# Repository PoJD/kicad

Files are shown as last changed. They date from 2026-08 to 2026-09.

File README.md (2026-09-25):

# kicad

Printed circuit boards. A container for all projects, successor to the older
`eagle` repo.

KiCad 10 — text formats, readable diffs, ERC and DRC running in CI through
`kicad-cli` without a GUI. The CI container image tracks the local major
version, because KiCad refuses to open files written by a newer one.

## Boards

| Board | Status | Description |
|---|---|---|
| [`canfuel/`](canfuel/) | design finished, `fab/` generated | fuel consumption converter for a VW PQ34 car, powered from the display it feeds |

The `canfuel` board is finished: schematic and PCB complete, ERC and DRC clean
with zero unconnected items, 24 parts on 55 × 45 mm and two layers, `fab/`
generated and committed. ⚠ **While a fabrication order is outstanding, do not
edit the board files** — `fab/` describes the commit that was sent, and an edit
makes it stop describing what is being made.

The harness is built, fitted and measured —
[`canfuel/docs/harness.md`](canfuel/docs/harness.md) is the procedure. **The
whole build path, across all three repositories, is
[`canfuel/docs/firmware/install.md`](https://github.com/PoJD/canfuel/blob/main/docs/firmware/install.md);**
the steps this repository owns are the board and the loom.

## Prerequisites

| For | What | Notes |
|---|---|---|
| opening and editing | **KiCad 10.x** | the **major** version matters, see below |
| the checks | **`kicad-cli`** | installed with KiCad, no separate download |
| `tools/check-*.py` | **Python 3** | no third-party packages |

```
kicad-cli version          # must print 10.x
```

**The major version is not a preference.** KiCad refuses to open files written
by a newer major version, so a mismatch is a hard failure rather than a
warning. CI runs the `kicad/kicad:10.0` container image and that image tracks
whatever is installed locally — bump the two together, never separately.

Nothing here needs a licence, an account or a plugin. Making the board also
needs no KiCad at all: `fab/` is generated and committed, so a fab house can be
given those files directly.

## Layout

```
lib/                symbols and footprints shared across projects
<board>/
  *.kicad_pro       project
  *.kicad_sch       schematic
  *.kicad_pcb       board
  fab/              gerbers, BOM, CPL — committed
  docs/             design documents, datasheets, and how to build the harness
```

For the `canfuel` board specifically, `canfuel/docs/` holds:

| File | Contents |
|---|---|
| `harness.md` | **making the loom and wiring it into the car** — a checklist, with the crimping, the connector cavities and the fuse |
| `pinout.md` | one-page reference for all three connectors |
| `harness-*.svg` | the connector and the four nets drawn from the real pad coordinates in `canfuel.kicad_pcb`, so they cannot disagree with the board |
| `assembly-orientation.svg` | **the figure to have open while soldering** — both sides of the board, and which way round each of the five parts that can go in backwards goes |
| `solder-check.md` | **after each joint** — for every pad on the board, where the meter must read zero and what it must stay open to, with the gap in millimetres |
| `implementation-plan.md` | how the board was designed, every number cited to a datasheet |
| `*.pdf` | the manufacturers' datasheets, listed in `NOTICE` as theirs |

`*.kicad_prl` is local state and does not belong in the repo (it is gitignored).

`fab/` is committed deliberately even though it is generated: for any board
that has been ordered it must be possible to find out exactly what was sent to
the fab.

## CI

`kicad-cli sch erc` and `kicad-cli pcb drc`. Both must pass before boards are
ordered. The workflow **fails if it finds no design files**, so a green run
always means something was actually opened and checked.

Two project-specific checks run alongside them: `check-netlist.py` and
`check-placement.py`.

## Related repositories

The `canfuel` board is one third of a project that needs all three
repositories. Clone them side by side.

**Building one?** [`canfuel/docs/firmware/install.md`](https://github.com/PoJD/canfuel/blob/main/docs/firmware/install.md)
is the whole path from three clones to a working device, in the order it has to
happen. Making up the harness — the part that lives in this repository — is
step 3 of seven.

| Repository | What it holds | Go there for |
|---|---|---|
| **`kicad`** (this one) | the converter board | the schematic, the PCB, `fab/`, and **`canfuel/docs/harness.md` — how to make the loom and wire it into the car** |
| [`canfuel`](https://github.com/PoJD/canfuel) | the converter firmware | building and flashing the hex, what the LEDs mean, how the car's frames are decoded |
| [`mfd15`](https://github.com/PoJD/mfd15) | the display configuration | the TRI file the display runs and how to upload it |

**The coupling to `canfuel` is the pin assignment**, and it is one-way: the
firmware is written against the board, not the other way round. Changing it
means changing the firmware in the same breath, and invalidates any `fab/`
already sent.

## Licence

[Apache License 2.0](LICENSE). Use it, change it, order the boards, sell them —
the only obligations are to keep the copyright and licence notices and to say
what you changed.

**`NOTICE` lists what is not ours.** The manufacturer datasheets under
`canfuel/docs/` belong to their manufacturers and are redistributed for
reference only; the licence above does not cover them and does not claim to.
Everything else in this repository is covered.

Questions, corrections and pull requests are welcome as issues on any of the
three repositories, or by email to Lubos Housa <luboshousa@gmail.com>.

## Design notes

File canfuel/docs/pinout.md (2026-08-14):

# Connector pinout

The one page to look at when a wire is in your hand and you need to know which
cavity it goes in. It covers the three connectors this project touches: the two
plugs on the MFD15 and the plug that goes onto the converter board.

Connector pinout

**Every view is the rear / cable side of the connector**, which is the
convention the MFD15 manual sets and the only one worth having: it is the view
you have in front of you while you push crimps in. Section 2 of the manual puts
it plainly — *"All pinout diagrams show the rear/cable side of the connector.
Pin the wires exactly as shown in this view — do not mirror or rotate them."*
The same rule applies to everything below.

**Go by the latch, and the numbering stops looking arbitrary.** Every one of
these housings numbers from the corner away from the latch: circuit 1 sits
bottom right when the latch is up. Plugs A and B on the MFD15 have the latch
up, so they read `A4 A3 / A2 A1` and `B6 B5 B4 / B3 B2 B1` — pin 1 bottom
right. **Plug C is mounted upside down on the MFD15 body**, latch down, so the
same rule puts pin 1 top left and the numbers run `C1…C6` along the top. It is
one rule seen from two ways up, not two conventions, and the latch in each
drawing is what tells you which. The converter plug has its latch up, like A
and B.

The latch positions were read off the hardware, not off a drawing — no document
in either repository states them.

---

## Plug C — Molex 43025-1200, on the MFD15

Twelve circuits, of which this project uses four.

| Pin | Signal | Ours | Wire |
| --- | --- | ---- | --- |
| C6  | 5 V | yes  | red |
| C7  | CAN H  | yes  | white  |
| C8  | CAN L  | yes  | yellow |
| C12 | SGND | yes  | black  |

The other eight (C1 MPP 1, C2 AIN1, C3 AIN2, C4 AIN3, C5 AIN4, C9 AIN5,
C10 AIN6, C11 MPP 2) belong to the display and are not wired here.

**C7 and C8 were already crimped and are not to be disturbed** — they are the
display's own CAN pins. C6 and C12 are the two sockets this project adds.

## Plug B — Molex 43025-0600, on the MFD15

| Pin | Signal | Ours |
| --- | --- | ---- |
| B5  | 12 V | no |
| B6  | GND | no |
| B1–B4 | USB | no |

This is the display's own supply from the car. **Nothing on plug B feeds the
converter** — the converter's 5 V comes from plug C, and the 12 V branch was
dropped from the board design.

## Converter plug — Molex 43025-0400

Mates with J1 or J2 on the canfuel board; both headers are on the same four
nets, so either will do.

| Circuit | Net  | Wire | From |
| --- | ---- | --- | --- |
| 1 | +5V  | red | plug C6 (through the fuse) |
| 2 | SGND | black  | plug C12 |
| 3 | CANH | white  | plug C7  |
| 4 | CANL | yellow | plug C8  |

Circuits 1 and 2 are the row nearest the PCB; 3 and 4 the row further from it.
The latch is up and the moulded `1` is the bottom right cavity, so **3 sits
directly above 1 and 4 diagonally from it**.

---

## Where these numbers come from

- **The converter plug's signal names are read out of `canfuel.kicad_pcb`**,
  not typed in — the figure is generated from the pad nets of J1, so it cannot
  drift from the board. The order itself is fixed by implementation-plan 3.4.
- **Plugs B and C are transcribed from the MFD15 Gen2 manual Rev 1.0**,
  section 2 and Figure 1, in the sibling repository at
  `mfd15/docs/manual-mfd15-gen2.pdf`. The manual is the authority; if this page
  ever disagrees with it, the manual wins and this page is the bug.
- **C6 = 5 V and C12 = SGND were confirmed with a multimeter** (5.01 V). That
  is a fact about the car, not about a part, so it is settled by measurement —
  see the sourcing rule in the top-level `CLAUDE.md`.

- **The latch positions are observed**, on the plugs and on the display body.
  They are the only thing on this page with no document behind them, and they
  are also what makes the rest of it legible.

**One useful cross-check fell out of the manual.** The display's own plug A is
a Molex **43025-0400** — the same housing as the converter plug — and Figure 1
draws it, cable side, as `A4 A3` over `A2 A1`. Circuit 1 bottom right is
exactly how the physical housings are moulded, so the cavity layout is now
corroborated by a document rather than resting on convention alone.

What that still does not prove is that circuit *n* of the receptacle mates with
circuit *n* of the header — that much is Micro-Fit convention, and no datasheet
in this repository states it. **Ringing circuit 1 out to the board's +5V pad
before the first power-up is what closes it**, and it takes a minute. Swapping
CAN H and CAN L only stops the bus working; a CAN wire in circuit 1 or 2 meets
5 V, which plan 3.4 calls a dead transceiver.

## See also

- `harness.md` — building the loom, step A4a for fitting these crimps
- `car-wiring.md` — the fourth connector, the 12 V 4-pin between the car and the
  display's harness, and which colour is tapped where in the car
- `harness-connector.svg` — the plug and the board pads side by side
- `harness-nets-on-pcb.svg` — the same four nets on the real copper
- `implementation-plan.md` 3.4 — why the pin order is what it is

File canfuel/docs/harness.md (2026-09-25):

# Building the harness

The loom that connects the MFD15 to the car and to the converter board. It
carries two things: the CAN pair from the cluster to the air vent, and 5 V from
the display's own plug C to the converter.

> **Built, fitted and measured on a reference vehicle.** The dashboard came
> apart, the old loom came out, and a complete new one went in — longer 12 V
> and ground into the display's plug B, the CAN pair and the 5 V/SGND run
> terminating in the Micro-Fit that the converter board plugs into.
> **5.01 V measured at the 4-pin itself**, which is the number that
> matters: it is the supply the board will see, through the fuse and both
> splices, not a reading taken at plug C before the loom existed. The display
> was then run on this loom with the CAN pair on DuPont jumpers in place of the
> board, and it worked.
>
> **What this document does not cover is the board**, only the loom. See
> `canfuel/docs/firmware/install.md` step 4.
>
> The checkboxes below are deliberately left unticked: this is the procedure
> for building one, and everything learnt while building ours has been folded
> back into the steps rather than recorded as ticks. The one place ours
> deviates from the plan is D2, and it says so there.

**The measuring and the sniffing are done.** The supply was checked at C6/C12
and reads 5.01 V, the TRI file loads and the logs were taken. Everything that
was in this document about proving those points has been removed — what is left
is how to make the loom.

**The car-side 4-pin connector is settled too.** It exists and is already
fitted; this is a re-crimp onto longer wires, not a new connector choice.
`car-wiring.md` records what each of its wires is and where it is tapped in the
car — its circuit order is **not** the converter plug's, so read it before
assuming.

**What you need:** crimping pliers, pin extractors, multimeter, spare ACI pins,
spare Micro-Fit 43030 sockets, butt splices with adhesive-lined heat shrink,
cable ties, fabric loom tape.

---

## A. On the bench — making up the loom

- [ ] **A1. Test crimp on an ACI pin first.** Take a spare pin and crimp it
  onto 0.5 mm² FLRY with the pliers (second jaw position, 22–18 AWG). Pull on
  the wire — it must hold. Slide on the yellow seal, insert it into the
  housing; it must click and the red lock must go on.
  - ❗ If it does not hold, you need a second pair of pliers for waterproof
    connectors. Find that out now, on the bench, not with the dashboard in
    pieces.
- [ ] **A2. Cut the new wires.** Red and black for the power run to plug B,
  yellow and white for the long CAN run from the cluster to the air vent. Err
  on the long side — shortening is always possible and this is a re-crimp
  precisely because the first set came out short.
- [ ] **A3. Twist the CAN pair** along its whole length.
- [ ] **A4. Crimp the ends.** ACI pins on the car side, Micro-Fit 43030 sockets
  on the housing side. Tug every one by hand.
- [ ] **A4a. Fit the sockets into the 4-pin Micro-Fit housing (43025-0400) in
  the right cavities.** The order is fixed by plan 3.4 and matches the pads of
  J1/J2 on the board. **Work it out before crimping, not mid-build.**

  | Micro-Fit circuit | Net  | Wire   | Plug C |
  | ----------------- | ---- | ------ | ------ |
  | 1                 | +5V  | red    | C6     |
  | 2                 | SGND | black  | C12    |
  | 3                 | CANH | white  | C7     |
  | 4                 | CANL | yellow | C8     |

  **Find the cavities from the moulded `1`, not by counting from an end** —
  seen from the wire side the numbering is the mirror of what it is from the
  mating face, so counting is exactly how this gets swapped. Circuits 1 and 2
  are the row the `1` belongs to; 3 and 4 are the other row, with **3 directly
  across from 1** and 4 diagonally opposite it. So the white wire goes across
  from the `1`, the yellow one diagonally from it.

  On the housings actually bought (moulded `MSH`), held wire-side towards you
  with the board header behind, the `1` is the **bottom right** cavity, so:

  ```
      4 CANL yellow    3 CANH white     upper row
      2 SGND  black    1 +5V   red      lower row, nearer the PCB
  ```

  That is the same way round as the board: J1/J2 pad 1 (+5V) is the right-hand
  pad of the row at the board edge and pad 3 (CANH) sits directly behind it,
  because the lower row of a right-angle header is the one nearest the PCB.

  `pinout.md` next to this file is the one-page connector reference for all
  three plugs, drawn the way the MFD15 manual draws its own.
  `harness-connector.svg` draws both — it is generated from
  the pad coordinates in `canfuel.kicad_pcb`, not drawn by hand, so it cannot
  disagree with the board. `harness-nets-on-pcb.svg` is the same four nets
  drawn on the real copper, turned the way up the 1:1 paper print comes out.

  **On a bare board the two pairs can be told apart by eye**: +5V is routed at
  0.8 mm and CANH/CANL at 0.4 mm, so the fattest tracks leaving the connectors
  are the power pair. SGND has no track at all — it is entirely the pour.

  ❗ Swapping CANH and CANL only stops the bus working. Putting a CAN wire in
  circuit 1 or 2 puts **5 V on it** — plan 3.4 calls that a dead transceiver.
  So **ring circuit 1 out to the board's +5V pad before the first power-up**,
  which is also the only check that catches a housing whose numbering does not
  follow the header's.
- [ ] **A5. Fit two sockets (5 V, SGND) into the existing 12-pin housing of
  plug C**, positions C6 and C12. **Do not touch C7/C8** — those are the
  display's CAN pins and they are already right.
- [ ] **A6. Ring everything out.** Every wire end to end, and no short between
  adjacent positions. Do this before the fuse goes in, so that a later failure
  has only one new thing to blame.

## B. On the bench — the 5 V fuse

The converter takes 5 V straight from the display, so a short on the converter
board is a short across the MFD15's 5 V rail. The fuse ends that. It is in the
loom rather than on the board because no 5 × 20 holder fits on a finished
55 × 45 mm PCB — plan 9.2 has the measurements and the reasoning.

**Parts:** SIBA 179120.0.2, 200 mA 250 V 5 × 20 mm glass, **time-lag T** — not
the fast F version — in inline cable holder K23411, which comes with 200 mm of
lead. The holder body is about 46 mm long and 10.5 mm across, so it needs a
straight run of loom that length and somewhere it can be unscrewed.

- [ ] **B1. Cut the 5 V wire only**, a short way back from the 4-pin connector
  at the air vent end. Leave the ground wire whole. Place the cut so the holder
  ends up in the length of loom that comes out when the MFD15 is pulled — the
  whole point is that the fuse can be changed without dismantling the dash.
- [ ] **B2. Join each cut end to one lead of the holder.** Crimp butt splices
  with adhesive-lined heat shrink are the right way. Soldering is acceptable if
  the joint is then sleeved well past the wick on both sides — a soldered joint
  in a loom that vibrates cracks exactly at the edge of where the solder
  travelled.
- [ ] **B3. Cable-tie the holder to the loom** so it cannot swing and chafe
  against the vent housing.
- [ ] **B4. Ring it out again** — continuity from plug C position C6 through to
  the 4-pin, with the fuse fitted. Then pull the fuse and confirm the circuit
  really does open. That second half is the one worth doing: it proves the fuse
  carries the current and that no splice quietly bypasses it.

## C. In the car — routing

- [ ] **C1. Take the dashboard apart** (radio, centre panel).
- [ ] **C2. Route the long CAN run** from the cluster to the air vent, so that
  the connector can be pulled out of the vent.
- [ ] **C3. Route the power wires** from the car's 4-pin to plug B. **This is
  12 V for the MFD15 itself, not for the converter.** The converter's 5 V comes
  from plug C at C6/C12 and never touches plug B — the 12 V branch was dropped
  from the board design, so nothing in this step feeds the converter.
- [ ] **C4. Do not tape anything up yet.** Loom it right at the end, once
  everything is in place and reaches.

## D. Finishing

- [ ] **D1. Tape up the looms and tidy the routing.** Use **fabric loom tape,
  not PVC insulating tape** — at dashboard temperatures PVC adhesive creeps,
  which is the same reason the board is not taped down either.
- [ ] **D2. ~~Wrap up to the fuse holder and start again after it.~~
  Overridden on the build: the holder is wrapped over as well.** The intent
  was that the fuse could be changed without unwrapping anything. On the
  actual holder one end leaves **bare 5 V exposed**, and bare metal loose
  behind a dashboard was judged the worse of the two risks, so it is taped
  over along with the rest of the loom.

  **What that costs:** changing a fuse now means peeling the tape back and
  re-wrapping it. So **the spare fuse in the car is not enough on its own —
  a roll of the fabric tape has to travel with it**, or the roadside repair
  cannot be finished.

  The alternative, if this is ever rebuilt: sleeve only the exposed end and
  leave the holder body outside the tape, which gets both. Not worth
  dismantling a finished loom for.
- [ ] **D3. Reassemble the dashboard.**

---

## If the fuse blows

The fault is on the converter board, not in the display. Fit one new fuse — and
carry a spare **and a roll of the fabric tape**, because the holder is wrapped
over (see D2) and a blown fuse behind the dash with nothing to hand is a wasted
trip. If the second one goes as well, stop replacing fuses and find
the short. That is what the fuse is telling you.

**What the fuse does not protect:** the run from plug C to the fuse itself.
That is deliberate — it lies inside the dashboard and does not move, and
covering it would mean putting the fuse somewhere you cannot reach.

## If a crimp will not hold

Stop and sort the tool out before going any further. A crimp that needs
persuading on the bench is a crimp that will let go in the car, and everything
downstream of this loom is inside a dashboard.

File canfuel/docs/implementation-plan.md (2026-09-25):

# canfuel — implementation plan

How to get from an empty repository to an ordered board. The requirements in
the root `CLAUDE.md` are the input and are treated as settled; this document
turns them into reference designators, nets and pin numbers.

Read the killer checks in section 3 before drawing anything.

**This is a design reference, not a progress tracker.** What is left to do in
the project as a whole lives in one place:
[`canfuel/docs/firmware/install.md`](https://github.com/PoJD/canfuel/blob/main/docs/firmware/install.md).

> ⚠ **This document was written before the board was drawn, and the board is
> now made.** Most of it is still the reference — the pin table in 4.2, the
> footprints in 4.7, the fab commands in 6 — but where the design moved after
> the plan was written, the plan has been corrected in place rather than
> rewritten, with the old text quoted and dated so a decision cannot be mistaken
> for an oversight.
>
> **The big one is the escape header J4**, removed because routing put a number
> on what it cost: eight unroutable connections, five of them nothing to do
> with the escape signals. Section 5.4 is the full account, and
> `canfuel/docs/firmware/refuted.md` entry D1 is the short one. Fourteen pins that this
> document originally sent to J4 now go **nowhere**, and driving them low is a
> firmware obligation — see 3.6.
>
> `canfuel/docs/firmware/refuted.md` collects every idea in this project that was
> believed and turned out wrong, across all three repositories.

**Every electrical number below is cited to a manufacturer datasheet**, per the
sourcing rule in `CLAUDE.md`. The three documents are in `docs/`:

| Short form | Document |
| --- | --- |
| `DS39977C` | Microchip, PIC18F66K80 family — `pic18f25k80-datasheet.pdf` |
| `DS20005167C`| Microchip, MCP2561/2 — `mcp2562-datasheet.pdf` |
| crystal d/s  | HC-49U/S DIP quartz crystal resonator — `crystal-datasheet.pdf` |
| Hitano EXR | C6's electrolytic — `hitano-exr-datasheet.pdf` |

Section 10 lists what has actually been read out of them, so the next person
can tell a checked number from an inherited one.

---

## 0. Prerequisites — done

- [x] **KiCad 10.0.5** installed to `C:\Program Files\KiCad\10.0`. The GUI,
      `kicad-cli.exe` and the standard symbol/footprint libraries all come from
      the one installer; there is no separate CLI download.
- [x] **`C:\Program Files\KiCad\10.0\bin\` added to the user PATH by hand.**
      The Windows installer does not do it (KiCad issue #19639), so without
      this `kicad-cli` only works inside the "KiCad Command Prompt" shortcut —
      fine interactively, useless for a script or a git hook. A shell that was
      already open when the PATH was edited still will not see it.
- [x] `kicad-cli version` prints `10.0.5`; `sch erc` and `pcb drc` both accept
      `--exit-code-violations`, which is what CI relies on.

**The major version is load-bearing.** KiCad cannot open files written by a
newer major version, so the CI image in `.github/workflows/kicad.yml` is pinned
to `kicad/kicad:10.0` to match. Upgrading one without the other breaks CI.

---

## 1. Project skeleton — done, its own commit

The project was created with the KiCad GUI (`File → New Project`) so the
generated files carry the correct schema versions; they are not hand-written.

```
canfuel/
  canfuel.kicad_pro
  canfuel.kicad_sch      empty
  canfuel.kicad_pcb      outline only
```

Board Setup, applied before any drawing:

| Setting | Value | Where it lives |
| --- | --- | --- |
| Layers | 2 (F.Cu, B.Cu) | `.kicad_pcb` `(layers)` |
| Copper thickness | 1 oz / 35 µm | `.kicad_pcb` `(setup (stackup))` |
| Board thickness | 1.6 mm | `.kicad_pcb` `(general (thickness))` |
| Minimum track width  | 0.20 mm | `.kicad_pro` `design_settings.rules` |
| Minimum clearance | 0.20 mm | same |
| Minimum via | 0.6 mm pad / 0.3 mm drill | same |
| Minimum hole/annulus | 0.30 mm / 0.15 mm | same |

**The board outline is in this commit too**, ahead of section 5.1. It has to
be: DRC reports `invalid_outline` as an error on a board with no Edge.Cuts
edges, so without it the skeleton commit could not be CI-green. It is the
settled 55 × 45 mm with R2 corners, origin at (50, 50) on the sheet. The four
M3 mounting holes went in later, once dropping the enclosure (section 9.1) made
their positions ours to choose.

**Definition of done:** CI green on a repository that contains an empty
schematic and a board that is an outline and nothing else. ✔

---

## 2. Parts and reference designators

> **Naming note.** The display's connector pins are called C6, C7, C8, C12 in
> the requirements. Capacitors on this board are also C-something. Below,
> connector pins are always written as **plug C pin 6**, never `C6`.

| Ref | Part | Package / footprint | Note |
| --- | --- | --- | --- |
| U1 | PIC18F25K80 | PDIP-28, **narrow 7.62 mm** socket | in a socket, never soldered direct |
| U2 | MCP2562-E/P | DIP-8 socket | in a socket. `-E/P` is the DIP part |
| Y1 | 16 MHz crystal, CL = 20 pF  | HC-49/S | **CL must be specified** — see 3.2 |
| C1, C2 | 33 pF C0G | 2.54 mm THT | **33 pF, not 22 pF** — see 3.2 |
| C3 | 100 nF X7R | 2.54 mm THT | U1 VDD (pin 20) |
| C4 | 100 nF X7R | 2.54 mm THT | U2 VDD (pin 3) |
| C5 | 100 nF X7R | 2.54 mm THT | U2 VIO (pin 5) |
| C6 | 10 µF electrolytic, 16 V | 5 mm THT radial | supply input; **105 °C part** — see 7  |
| C7 | 10 µF X7R, 16 V, **Murata GRM32DR71C106KA01L** | 1210 SMD | **mandatory** — U1 VDDCORE/VCAP, see 3.5 |
| C8 | 100 nF X7R | 2.54 mm THT | MCLR reset hold, behind JP2 — see 4.3a |
| R1 | 10 kΩ | 1/4 W THT | MCLR pull-up |
| R2 | 10 kΩ | 1/4 W THT | RA0 pull-down (debug jumper) |
| R3, R4 | 1 kΩ | 1/4 W THT | LED series resistors — see 3.6 |
| R5 | 120 Ω | 1/4 W THT | **DO NOT FIT** — see 3.3 |
| R6 | 470 Ω | 1/4 W THT | MCLR series — see 4.3a |
| D1 | LED **red** | 3 mm THT | power / heartbeat. Colour is free — see CLAUDE.md |
| D2 | LED yellow | 3 mm THT | CAN status |
| J1, J2 | Molex Micro-Fit 3.0 43045-0400 | right-angle, board mount | wired in parallel — see 3.4 |
| J3 | 5-pin header 2.54 mm | 1×5 | ICSP |
| ~~J4~~ | ~~2×8 header 2.54 mm~~ | — | **removed — see 5.4** |
| JP1 | 2-pin header + jumper | 1×2 | debug enable on RA0 |
| JP2 | 2-pin header + jumper | 1×2 | isolates C8 for programming — see 4.3a |
| — | DIP-28 socket, narrow | | not in `canfuel-bom.csv` — see 7 |
| — | DIP-8 socket | | not in `canfuel-bom.csv` — see 7 |

---

## 3. The things that quietly kill this board

Check each one twice while drawing, and again during the ERC pass. All of them
are now on the sheet as drawn, and all of them are repeated as numbered notes
in the schematic's own notes panel so they survive without this file.

### 3.1 MCP2562 VIO and STBY

The single easiest mistake in the design. Without these the transceiver sits in
standby and transmits nothing, while everything else measures fine.

**STBY floating is not neutral — it is Standby.** DS20005167C section 1.7.9:
STBY carries an internal MOS pull-up to VIO, typically 660 kΩ at 5 V. An
unconnected pin 8 therefore reads high, and section 1.1.2 says a high on STBY
switches the transmitter off. That is why pin 8 is tied hard to SGND rather
than left to a resistor or a jumper that assembly could skip.

The datasheet's own application circuit (Figure 1-2) drives STBY from an MCU
pin instead, which buys a low-power standby mode. **We deliberately do not**:
the board is powered only while the display is, and total draw is under 30 mA
against a 0.5 A budget, so standby is worth nothing here and a hard ground
removes a whole class of failure.

MCP2562 DIP-8 pinout, from DS20005167C page 1 (package types) and Table 1-2:

| Pin | Name | Connect to |
| --- | ---- | --- |
| 1 | TXD  | U1 RB2 (CANTX), pin 23 |
| 2 | VSS  | SGND |
| 3 | VDD  | +5V (with C4 across pins 3–2) |
| 4 | RXD  | U1 RB3 (CANRX), pin 24 |
| 5 | VIO  | **+5V** (with C5 to SGND) |
| 6 | CANL | CANL |
| 7 | CANH | CANH |
| 8 | STBY | **SGND** |

Do not leave pin 8 floating and do not leave pin 5 unconnected on the
assumption it is optional. Tie them hard — no pull-ups, no jumpers, nothing
that could be left off during assembly.

VIO is a supply, not a logic input: DS20005167C 2.2 gives its range as
1.8–5.5 V, and 1.1.2 notes the bus wake-up needs **both** VDD and VIO in range.
Figure 1-2 shows 0.1 µF on each — that is C4 and C5. VDD itself is specified
4.5–5.5 V, so the 5 V rail sits mid-range.

### 3.2 Crystal loading is 33 pF

C1 = C2 = **33 pF** C0G/NP0, not the 22 pF that gets fitted by reflex, and not
X7R.

The number comes out of the crystal datasheet rather than habit. That sheet
gives **Loading Capacitance: 20 pF Std., 8 to 33 pF**, and its own part-number
example for this frequency — `FTX16.000M20S-30/30B` — is a 16.000 MHz part with
CL = 20 pF in the HC49/S package. So:

```
CL = C1·C2/(C1+C2) + Cstray,  and with C1 = C2 = C:
C  = 2·(CL − Cstray) = 2·(20 − 5) = 30 pF  →  33 pF from the E12 row
```

Cstray of about 5 pF is the usual allowance for the pads, tracks and pin
capacitance on a through-hole board of this size.

> **An earlier version of this document said CL = 32 pF.** That figure appears
> nowhere in the crystal datasheet and does not survive the arithmetic above —
> a 32 pF crystal would want about 56 pF, and 33 pF caps would have run it
> fast. The capacitor value was right for the wrong reason, which is exactly
> the failure mode the sourcing rule in `CLAUDE.md` exists to catch.

Two independent confirmations that 33 pF is the right pairing: the calculation
above, and `PoJD/can-pcb` — `CanSwitch.sch` and `CanRelay.sch` both run a
16 MHz HC49/S with 33 pF and have worked for years.

**No series resistor on OSC2.** DS39977C Table 3-3 note 2 says an Rs "may be
required to avoid overdriving crystals with low drive level specification", and
this crystal's drive level is 100 µW typical, 500 µW maximum. Whether it is
actually needed cannot be decided from the datasheets — it takes a measurement
on a built board. The same PIC-family part drives the same crystal without Rs
in `can-pcb`, so none is fitted. If the oscillator misbehaves, a series
resistor has to be tacked in at the socket pins, which are through-hole and
reachable from underneath.

Microchip's own tables are guidance only and do not cover this case directly:
Table 3-3 (crystals, HS) lists 27 pF at 4 MHz, 22 pF at 8 MHz and 15 pF at
20 MHz with no 16 MHz row, and note 3 defers to the crystal manufacturer for
the right values. That is what the derivation above does.

### 3.3 No 120 Ω termination

The car's bus is already terminated at both ends. A third resistor overloads
it. R5 gets a footprint and silkscreen, and is **not fitted**:

- Place R5 across CANH/CANL near U2. Done — (85.52, 91.5).
- Silkscreen next to it: `120R DNF`. Done — a board-level `gr_text` at
  (93.2, 91.5), added when the 6 pre-order check found it missing. It is not
  part of the R5 footprint, so re-running `import-footprints.py` cannot take it
  away again.
- Mark it `Do not populate` in the symbol's fields so it drops out of the BOM.
  Done — `in_bom no` and `dnp yes`; it is in neither `canfuel-bom.csv` nor
  `canfuel-cpl.csv`.

A separate solder jumper is not worth the area — for a bench test the resistor
has to be soldered in anyway, and an unpopulated footprint is exactly as quick.

### 3.4 Both Micro-Fit headers in parallel

J1 and J2 sit on the same four nets: CANH, CANL, +5V, SGND. Pin *n* of J1 goes
to pin *n* of J2. This is intentional: cables become interchangeable and the
board is a CAN pass-through even with U1 pulled out of its socket.

| Micro-Fit pin | Net  | Harness |
| --- | ---- | --- |
| 1 | +5V  | plug C pin 6 |
| 2 | SGND | plug C pin 12 (SensorGround) |
| 3 | CANH | plug C pin 7 |
| 4 | CANL | plug C pin 8 |

Fix this pin order once, here, and keep the harness (`harness.md`) consistent
with it. Getting +5V and CANH swapped is a dead transceiver.

### 3.5 VDDCORE/VCAP needs 10 µF — and pin 6 is not a port pin

Settled against the datasheet (DS39977C, section 2.4 "Voltage Regulator Pins",
section 28.3 and Table 31-4). Two things follow, and both are easy to get
wrong from memory:

**There is no ENVREG pin.** Not on the 28-pin package, not anywhere in the K80
family. On PIC18F parts (as opposed to PIC18**LF**) the on-chip 3.3 V core
regulator is *permanently enabled* — there is nothing to tie and no way to
disable it. VDD stays at 5 V and the I/O is 5 V; only the core runs at 3.3 V.

**Pin 6 is VDDCORE/VCAP, not RA4.** The 28-pin K80 has no RA4 at all. Pin 6
needs C7:

- **10 µF, low-ESR (< 5 Ω)**, ceramic or tantalum, from pin 6 to SGND.
  Table 31-4 gives CEFC as min 4.7 µF, typ 10 µF.

  **The fitted part is a Murata GRM32DR71C106KA01L**, 10 µF X7R 16 V in 1210 —
  one of the four Microchip names in Table 2-1, so no equivalence argument has
  to be made at all. Its ESR is tens of milliohms against a 5 Ω limit, and X7R
  in a 1210 case loses little enough to DC bias at 3.3 V to stay well clear of
  the 4.7 µF minimum.

  It is the only SMD part on the board, which is a deliberate trade. A dipped
  tantalum was the obvious through-hole alternative and was rejected: the CA42
  datasheet gives DF = 6 % at 100 Hz for the 10–68 µF range, which works out at
  9.6 Ω there and **specifies no high-frequency ESR at all**. The real figure
  is probably 2–3 Ω and `PoJD/can-pcb` has run one for years, but "probably"
  is not a specification, and this is the component whose failure mode the rest
  of this section describes as intermittent and nasty to debug. A tantalum
  would also have to become `C_Polarized` with polarity on the silkscreen —
  `can-pcb` drew its as a non-polarised `C-EU`, which worked only because the
  builder knew which way round it went.
- ⚠ **Pin 6 must never be connected to VDD.** That is the regulator's output,
  not an input. Tying it to 5 V destroys the part.
- Keep the trace to the capacitor **under 6 mm** (datasheet: 0.25 inch).

Without C7 the regulator is unstable and the part browns out or never starts —
and because the symptom is intermittent it is a genuinely nasty one to debug.

**The 0.1 µF figure is real but belongs to a different part.** DS39977C 2.4
gives it twice: once for "when the regulator is disabled", and once for the
PIC18**LF**XXKXX devices, which disable the regulator permanently. Our part is
an F, where 2.4 says the regulator is permanently *enabled* and "these devices
require a 10 µF capacitor on the VCAP/VDDCORE pin". Reading the sentence that
applies to the neighbouring part number is how a board ends up with 0.1 µF
there.

**Available port A pins.** With the crystal on pins 9/10, RA6 and RA7 are gone
and pin 6 is not a port pin, so port A offers exactly five usable pins:
**RA0 (2), RA1 (3), RA2 (4), RA3 (5), RA5 (7)** — of which RA0 is the debug
jumper. Port A is tight, and by 3.6 it is also weak; do not plan on more.

### 3.6 Port A can only drive 2 mA — the LEDs are on port C

DS39977C page 541, Absolute Maximum Ratings, splits the ports:

| Pins | Max sourced | Max sunk |
| --- | --- | --- |
| PORTA<7:6>, any PORTB, any PORTC  | 25 mA | 25 mA |
| **PORTA<5:0>**, PORTF, PORTG | **2 mA** | **2 mA** |

RA1 and RA2 are inside PORTA<5:0>. An LED at 1 kΩ off a 5 V rail draws about
2.2 mA once VOH is taken as VDD − 0.7 (D090) and Vf as 2.1 V — over the limit,
so **D1 and D2 are on RC0 (pin 11) and RC1 (pin 12)**, and RA1/RA2 were left
unused. R3 and R4 stay at 1 kΩ. (They "went to the escape header instead" until
J4 was removed, §5.4; on the manufactured board they go nowhere
and the firmware drives them low.)

Two things make this worth writing down rather than just fixing:

- **The datasheet contradicts itself and the stricter number wins.** D080/D090
  in the DC characteristics specify VOL and VOH for "PORTA, PORTB, PORTC"
  together, at IOL = 8.5 mA and IOH = −3 mA, which reads as permission to pull
  3 mA out of RA1. Absolute Maximum Ratings is a stress rating the manufacturer
  will not stand behind being exceeded; a characterisation table is not a
  licence to exceed it.
- **`can-pcb` was not a precedent for this.** Its status LED hangs off RC1
  through 1 kΩ — port C, 25 mA. The 1 kΩ was inherited from that board without
  the pin, and the pin was the part that mattered.

RA0 is unaffected: it is an input with a pull-down, and sources nothing.

### 3.7 J1/J2 — the Micro-Fit PCB layout, and why the holes are "finished"

`micro-fit-43045-datasheet.pdf` is Molex **SD-43045-001** (rev. 2016/08/23),
*Micro-Fit (3.0) Dual Row Right Angle Thru Hole Header Ass'y*. It was the last
part on the board with no datasheet on disk. Its `PCB LAYOUT: COMPONENT SIDE`
block settles four things that had only ever been taken from the KiCad
footprint:

| Drawing | Value | As built |
| --- | --- | --- |
| contact hole | ⌀ .040±.002 / **1,02±0,05 mm** TYP | 1.02 mm |
| peg hole | ⌀ .118±.002 / **3,00±0,05 mm** TYP | 3.00 mm NPTH |
| pitch | .118±.004 / 3,00±0,10 non-accum | 3.00 mm |
| row spacing | .170±.003 / 4,32±0,08 | ok |
| recommended board thickness | .062 / **1,57 mm** | 1.60 mm |
| mates with | receptacle series **43025** | 43025-0400 bought |

The pin itself is **.025 / 0,64 mm SQ TYP**, so its diagonal is 0.905 mm.

**Note 7 of the drawing is a placement rule and nobody had checked it:** *"To
avoid interference between receptacle and PCB, header must be placed within
.400/(10,16) max. from edge of PCB."* It limits how far the header may be set
back, so the mating receptacle does not foul the board. J1 and J2 courtyards
end **0.33 mm** from the bottom edge — effectively flush, against a 10.16 mm
limit. It passes with room, but it passes by luck rather than by design, so it
is written down now: if these connectors are ever moved inward, this is the
number that decides it.

**The holes must be ordered as finished sizes, not drill sizes.** A fab that
compensates for plating turns a 1.02 mm tool into a 0.92 mm finished hole,
which is below the drawing's 0.97 mm lower limit — out of spec. Asked the other
way the error is benign: a hole 0.1 mm too large loosens the pin and drops the
annular ring to 0.19 mm, still far above any fab's minimum. So "finished" is
both correct and the safe direction. See 6.1.

**The peg hole is the fussy one, and the answer is not a smaller number.** The
plastic peg is split and spreads under the board, so the instinct is to
undersize the hole for grip. Molex already allowed for that: ±0.05 mm is the
band the peg is designed to hold across. Moving the nominal down to 2.95 or
2.97 puts the low end of any normal fab tolerance under 2.95 and out of spec,
and forcing a split LCP peg into an undersized hole is how the housing cracks —
on a right-angle part the peg also carries the plug insertion force.

The real hazard is plating, not the nominal. A **plated** peg hole comes out at
about 2.90 mm, under the 2.95 minimum, which is exactly the "have to force it"
failure; and plating compensation wrongly applied to a hole that is not plated
gives 3.10 mm, where the peg does not grip at all. Both are avoided by shipping
PTH and NPTH as separate drill files and saying which is which — see 6.

---

## 4. Schematic — done

One A3 sheet. A4 was tried first and everything collided; the parts count is
low but the label count is not.

### 4.1 Nets

```
+5V      SGND      CANH      CANL
CAN_TX   CAN_RX    OSC1      OSC2
~MCLR    MCLR_RC   MCLR_C                (the reset network of 4.3a)
PGC      PGD       VCAP
LED_PWR  LED_CAN   DBG_EN                (LED_PWR/LED_CAN are RC0/RC1)
LED_PWR_A          LED_CAN_A             (resistor to LED anode)
CANTX2   CANRX2                          (RC6/RC7, the ECAN alternates)
ESC_RA1  ESC_RA2   ESC_RA3   ESC_RA5
ESC_RC2 … ESC_RC5
ESC_RB0  ESC_RB1   ESC_RB4   ESC_RB5
```

33 nets in total. `SGND` is the ground net name throughout, not `GND` — it is
the display's sensor ground and the harness documentation calls it that.

**The labels are global, not local.** On a single-sheet design either works
electrically, but a local label comes out of the netlist as `/CANH` while the
net classes in section 5.3 are written as `CANH`. A netclass pattern that
silently matches nothing is a bad way to find out that CAN was routed at the
default track width.

### 4.1a Symbol and footprint choices

| Ref | Symbol | Footprint |
| --- | --- | --- |
| U1 | `MCU_Microchip_PIC18:PIC18F25K80_ISS` | `Package_DIP:DIP-28_W7.62mm_Socket` |
| U2 | `Interface_CAN_LIN:MCP2562-E-P` | `Package_DIP:DIP-8_W7.62mm_Socket` |
| Y1 | `Device:Crystal` | `Crystal:Crystal_HC49-U_Vertical` |
| C1–C5 | `Device:C` | `Capacitor_THT:C_Disc_D5.0mm_W2.5mm_P5.00mm` |
| C6 | `Device:C_Polarized` | `Capacitor_THT:CP_Radial_D5.0mm_P2.00mm` |
| C7 | `Device:C` | `Capacitor_SMD:C_1210_3225Metric_Pad1.33x2.70mm_HandSolder` |
| R1–R5 | `Device:R` | `Resistor_THT:R_Axial_DIN0207_L6.3mm_D2.5mm_P10.16mm_Horizontal` |
| D1, D2  | `Device:LED` | `LED_THT:LED_D3.0mm` |
| J1, J2  | `Connector_Generic:Conn_02x02_Odd_Even` | `Connector_Molex:Molex_Micro-Fit_3.0_43045-0400_2x02_P3.00mm_Horizontal` |
| J3 | `Connector_Generic:Conn_01x05` | `Connector_PinHeader_2.54mm:PinHeader_1x05_P2.54mm_Vertical` |
| ~~J4~~  | ~~`Connector_Generic:Conn_02x08_Odd_Even`~~ | ~~`Connector_PinHeader_2.54mm:PinHeader_2x08_P2.54mm_Vertical`~~ — **removed, see 5.4** |
| JP1 | `Connector_Generic:Conn_01x02` | `Connector_PinHeader_2.54mm:PinHeader_1x02_P2.54mm_Vertical` |

Two of those deserve a sentence, because both look wrong at a glance:

- **U1 uses the `_ISS` (SSOP-28) symbol with a PDIP-28 footprint.** KiCad ships
  only `_ISS` and `_IML` for this part; there is no SPDIP variant. All three
  28-pin packages share one pinout, and the symbol's pins were checked
  one by one against DS39977C page 6 — including that pin 6 is `Vcap` and that
  there is no RA4. Nothing else in the library needed changing.
- **J1/J2 are `Conn_02x02`, not `Conn_01x04`.** The Micro-Fit 43045-0400 is
  physically two rows of two. Its pads are numbered 1, 2 across the first row
  and 3, 4 across the second, so the plan's pin numbering in 3.4 carries over
  unchanged — but the symbol has to be the two-row one or the pin numbers do
  not line up with the footprint.

### 4.2 U1 — PIC18F25K80, PDIP-28

The full 28-pin SPDIP pinout, taken from DS39977C page 6. Names abbreviated to
the functions that matter here.

| Pin | Name | Connect to |
| --- | --- | --- |
| 1 | MCLR/RE3 | R6 (470 Ω) from the R1 node, and J3 pin 1. See 4.3a |
| 2 | RA0/AN0 | JP1 to +5V, R2 (10 kΩ) to SGND → `DBG_EN` |
| 3 | RA1/AN1 | **nothing — see 3.6.** 2 mA pin |
| 4 | RA2/AN2 | **nothing — see 3.6.** 2 mA pin |
| 5 | RA3/AN3 | **nothing — see 3.6** |
| 6 | **VDDCORE/VCAP** | **C7 (10 µF low-ESR) to SGND. Never to +5V.** See 3.5 |
| 7 | RA5/AN4 | **nothing — see 3.6** |
| 8 | VSS | SGND |
| 9 | OSC1/CLKIN/RA7| Y1 + C1 |
| 10  | OSC2/CLKOUT/RA6| Y1 + C2 |
| 11  | RC0/SOSCO | R3 → D1 (`LED_PWR`) — see 3.6 |
| 12  | RC1/SOSCI | R4 → D2 (`LED_CAN`) — see 3.6 |
| 13  | RC2/T1G/CCP2  | **nothing — see 3.6** |
| 14  | RC3/SCL/SCK | **nothing — see 3.6** |
| 15  | RC4/SDA/SDI | **nothing — see 3.6** |
| 16  | RC5/SDO | **nothing — see 3.6** |
| 17  | RC6/**CANTX**/TX1 | **nothing — see 3.6.** Alternate ECAN pin, see below |
| 18  | RC7/**CANRX**/RX1 | **nothing — see 3.6.** Alternate ECAN pin, see below |
| 19  | VSS | SGND |
| 20  | VDD | +5V, C3 (100 nF) to SGND, as close as the layout allows |
| 21  | RB0/INT0 | **nothing — see 3.6** |
| 22  | RB1/INT1 | **nothing — see 3.6** |
| 23  | RB2/**CANTX** | `CAN_TX` → U2 pin 1 |
| 24  | RB3/**CANRX** | `CAN_RX` → U2 pin 4 |
| 25  | RB4/AN9 | **nothing — see 3.6** |
| 26  | RB5/T0CKI | **nothing — see 3.6** |
| 27  | RB6/**PGC** | `PGC` → J3 pin 5 |
| 28  | RB7/**PGD** | `PGD` → J3 pin 4 |

**The ECAN module can be remapped.** CANTX/CANRX are available on RB2/RB3
*and* on RC6/RC7.

⚠ **A remap is not two wire links on a header.** J4 was removed (§5.4), so
RC6 and RC7 go nowhere on the manufactured board, and moving the ECAN means
soldering to the PDIP socket pins from underneath — they are through-hole and
reachable, so the escape route survives, but it is a soldering iron and not a
jumper. That is the single strongest reason to get `CANMX` right the first
time, and it is why the firmware reads the bit out of the built hex rather than
trusting the source.

LEDs, driven by the PIC so nothing lights up in the car:

- D1 anode ← R3 ← RC0 (pin 11) → `LED_PWR`, cathode to SGND
- D2 anode ← R4 ← RC1 (pin 12) → `LED_CAN`, cathode to SGND

Port C, not port A — see 3.6, and do not move them back.

Firmware only drives them when `DBG_EN` reads high, i.e. when the JP1 jumper is
fitted. R2 pulls RA0 down, so an absent jumper is a defined low, not a floating
input.

**Unused pins are a firmware obligation, and since J4 went it is the only
option.** DS39977C 2.7 offers two: unused I/O configured as outputs driven low,
**or** a 1–10 kΩ resistor to VSS. There are no such resistors on this board —
fourteen of them would have cost more area than they were worth — so the first
option is the only one available, and the firmware in the `canfuel` repository
has to drive all fourteen low at start-up: RA1, RA2, RA3, RA5, RC2–RC7, RB0,
RB1, RB4, RB5.

⚠ **The fourteen pins go nowhere at all** — they do not sit at a header with
nothing on the other end; J4 was removed (§5.4). That makes the firmware
obligation more load-bearing, not less, because software is the only thing
standing between those pins and floating inputs.

### 4.3 J3 — ICSP

PICkit pin order, 2.54 mm, keep pin 1 square-padded and marked on silkscreen.
Keep the J3-to-U1 traces short; the datasheet (2.5) explicitly rules out
pull-ups, series diodes and capacitors on PGC/PGD because they interfere with
the programmer.

| J3 pin | Signal |
| --- | --- |
| 1 | ~MCLR / VPP |
| 2 | +5V |
| 3 | SGND |
| 4 | PGD (RB7) |
| 5 | PGC (RB6) |

**Source: DS51795B Figure 1-2, *PICkit™ 3 Programmer Connector Pinout***, in
`pickit3-users-guide.pdf`. It gives, verbatim: `1 = MCLR/VPP`, `2 = VDD Target`,
`3 = VSS (ground)`, `4 = PGD (ICSPDAT)`, `5 = PGC (ICSPCLK)`, `6 = PGM (LVP)`.

Two things that table does not say on its face:

- **Their connector is six pins, ours is five.** §1.2.4 calls it *"a 6-pin
  header (0.100" spacing)"*. Pin 6 is `PGM (LVP)`, low-voltage programming,
  which this project does not use — `pic_config.h` in `canfuel` has no `LVP`
  enabled and the PICkit drives VPP on pin 1. So J3 stops at five and pin 6
  simply has nowhere to land. A 6-pin programmer plug on a 5-pin header
  overhangs by one position, which is only safe **because the overhang is at
  the far end from pin 1** — align on the marker, not on the end of the header.
- **Pin 1 is found by the marker, not by counting.** §1.2.3: *"This marker
  designates the location of pin 1 for proper connector alignment."* Which is
  why pin 1 keeps a square pad and a silkscreen mark here.

⚠ **This citation arrived after the board was manufactured**, which is the
wrong order and worth saying. Until it did, the table above stood on the words
"PICkit pin order" and nothing else — the neighbouring citation to DS39977C
§2.5 covers pull-ups, series diodes and capacitors on PGC/PGD, a different
question, and §2.5 gives no connector pinout at all. The order was
independently confirmed by measurement first
(`canfuel/docs/firmware/install.md` step 4: pin 3 rings out at 0 Ω to the programmer's
USB shell, pin 2 carries the supply under `-W`), and the datasheet agreed with
it afterwards. **It agreeing is luck, not process.**

J3 pin 1 lands on `~MCLR`, the U1 pin itself, not on the RC node behind R6 —
the programmer drives the pin directly and R6 keeps C8 off its back. See 4.3a.

**Not fitted, but recorded:** 2.5 also suggests a series resistor of a few tens
of ohms, never above 100 Ω, on PGC and PGD if the ICSP connector is expected to
see an ESD event. This connector lives in a closed vent cavity behind the
dashboard and is touched perhaps twice in the board's life, so nothing is
fitted. Revisit only if the header is ever brought somewhere reachable.

### 4.3a MCLR — the full network of DS39977C Figure 2-2

```
+5V ──[ R1 10k ]──┬──[ R6 470R ]── MCLR (U1 pin 1) ── J3 pin 1
                  │      nets:  MCLR_RC ──R6──> ~MCLR
                 JP2
                  │   MCLR_C
              [ C8 100n ]
                  │
                SGND
```

Figure 2-1 lists MCLR among the pins that must always be connected, and
Figure 2-2 gives the shape above. Each part earns its place:

- **R1 = 10 kΩ.** Figure 2-2 note 1: "R1 ≤ 10 kΩ is recommended. A suggested
  starting value is 10 kΩ."
- **R6 = 470 Ω.** Figure 2-2 note 2: "R2 ≤ 470 Ω will limit any current flowing
  into MCLR from the external capacitor C, in the event of MCLR pin breakdown,
  due to Electrostatic Discharge (ESD) or Electrical Overstress (EOS)." It sits
  between the RC node and the pin, which is the only position from which it can
  do that.
- **C8 = 100 nF, behind JP2.** 2.3 recommends the capacitor for resistance to
  spurious resets from voltage sags, and in the same breath says it must be
  isolated from the pin during programming and debugging by a jumper, because
  device programmers drive MCLR and need fast edges. JP2 is that jumper.
- **All of it within 6 mm of pin 1.** 2.3: "Any components associated with the
  MCLR pin should be placed within 0.25 inch (6 mm) of the pin." That is a
  placement constraint on R1, R6, C8 and JP2 — see 5.2.

**Pull JP2 before programming, refit it afterwards.** This is the one assembly
step the board cannot enforce, so it is note 11 on the schematic as well.

An earlier version of this plan had only R1 and said "no capacitor on this pin",
reading 2.5 (which is about PGC and PGD) as if it covered MCLR. It does not:
2.3 asks for the capacitor and hands it a jumper. `PoJD/can-pcb` built the full
network — R1 10 kΩ, 470 Ω, 0.1 µF on a jumper — which is what prompted the
re-read.

### 4.4 Power

+5V and SGND enter on J1/J2. C6 (10 µF) across the input, C3/C4/C5 (100 nF) at
each supply pin. No regulator, no reverse-polarity diode, no TVS — that was
decided; the 12 V branch is not on this board. Total draw is under 30 mA
against the display's 0.5 A limit, so there is no thermal question to answer.

Both values are the datasheet's own:

- **100 nF, ceramic, low-ESR, within 6 mm of the pin** — DS39977C 2.2.1, which
  calls decoupling on every supply pin pair *required*, not advisable, and puts
  the same 0.25 inch limit on the track as 2.4 does for C7.
- **C6 = 10 µF is the tank capacitor of 2.2.2**, which asks for one on boards
  whose power traces run longer than six inches and gives a range of 4.7 µF to
  47 µF. The harness from the display connector is well past six inches, so
  this is the case that section describes.

The 28-pin package has no AVDD/AVSS pins — 2.1 insists they always be connected
"regardless of whether any of the analog modules are being used", but the pin
tables put them only on the 64- and 80-pin parts. Nothing is missing here; it
is worth stating so the question is not reopened.

### 4.5 ERC

```
kicad-cli sch erc --severity-all --exit-code-violations canfuel/canfuel.kicad_sch
```

Clean, zero violations at `--severity-all`. Three `PWR_FLAG`s were needed and
are on the sheet: `+5V` and `SGND` are fed by connector pins rather than a
regulator output, and `VCAP` is driven by the regulator inside U1, so ERC has
no power-output pin to find on any of the three. No ERC severity was lowered
and no check was disabled to get there.

### 4.6 Checking the schematic against this document

ERC proves the sheet is electrically well formed. It does not prove RB2 went
to TXD rather than RB3 — that was demonstrated, not assumed: swapping the two
labels produces a board that could never transmit, and ERC reports **zero**
violations on it, because both pins are bidirectional and nothing is
malformed.

So there is a second check, and it is in the repository:

```
python tools/check-netlist.py
```

It exports the netlist and compares every `ref.pin -> net` against the tables
in sections 3 and 4 above — 87 connections, 33 nets, 24 components, no pin in
the netlist unaccounted for and none missing. It catches the RB2/RB3 swap
above. Needs `kicad-cli` on PATH; exits nonzero on any mismatch.

It also carries weight this sheet cannot get from ERC for a second reason: the
project has *Global label only appears once in the schematic* switched off, so
a mistyped label name would produce two half-connected nets and no violation.
Every connection here is made by label, so that check is the one that would
have caught it.

Run it after any edit to the sheet. When the design changes on purpose, update
`EXPECT` in the script in the same commit — keeping the two in step is the
point of the file, not a chore it imposes.

**Definition of done:** ERC clean, netlist matches this document, committed,
CI green. ✔

---

## 5. PCB layout

### 5.1 Outline and constraints

- Board **55 × 45 mm**, 2 layers, corners rounded R2. Outline runs x 50…105,
  y 50…95 on the sheet.
- **Four M3 holes, ⌀3.2 mm non-plated, 4 mm in from each edge** — H1 (54, 54),
  H2 (101, 54), H3 (54, 91), H4 (101, 91), a 47 × 37 mm pattern. Keep copper
  and parts clear of a 7 mm circle around each.
- **There is no enclosure** (section 9), so those positions answer to nothing
  but themselves and are not a respin risk. Whatever the board is eventually
  mounted on adapts to them.
- **The holes live in the PCB only** — there are no `H1`…`H4` symbols on the
  schematic, because a mounting hole carries no net. If you ever run *Update
  PCB from Schematic* in the GUI, leave **Delete footprints with no symbols**
  unticked or they disappear. It is unticked by default.
- Available space in the vent is roughly 65 × 55 mm, depth unknown — the MFD15
  is in the way and cannot be measured around. The board's 55 mm therefore has
  about 10 mm of margin in the direction that was measured, which is the whole
  reason the enclosure was dropped.
- Height budget is generous with no lid to clear: the tallest parts are C6 at
  11 mm and Y1 standing at about 11.4 mm. Nothing needs to be laid down.
- Mostly through-hole; hand assembly. C7 is the one SMD part, on B.Cu.

### 5.2 Placement

```
        55 mm
  ┌───────────────────────────┐
  │  J3 ICSP                  │  ← top edge, reachable with the lid off
  │        (J4 was here, 5.4) │
  │                           │
  │   Y1  C1 C2               │
  │   ┌──────────┐            │  45 mm
  │   │    U1    │   D1  D2   │
  │   │  PIC28   │   JP1      │
  │   └──────────┘            │
  │        ┌──────┐   C6      │
  │   R5   │  U2  │           │
  │  DNF   └──────┘           │
  │   ┌────┐   ┌────┐         │
  └───┤ J1 ├───┤ J2 ├─────────┘  ← bottom edge, harness exits one way
```

Rules behind that sketch. The numeric ones are the datasheet's, and there are
now four of them rather than one — do the placement against this list, not
against the sketch:

- **C7 hard against U1 pin 6, track under 6 mm** — DS39977C 2.4. Place it
  before routing anything else. Being 1210 SMD it goes on **B.Cu directly
  underneath pin 6**, which takes the track from "under 6 mm" to about zero and
  costs no top-side area next to the socket. It is the only part on the bottom
  layer; keep the ground pour clear of it there.
- **C3 within 6 mm of U1 pin 20, C4 within 6 mm of U2 pin 3, C5 within 6 mm of
  U2 pin 5**, each on the same side of the board as its pin — 2.2.1. If a via
  is unavoidable the 6 mm still counts from pin to capacitor.
- **R1, R6, C8 and JP2 all within 6 mm of U1 pin 1** — 2.3, "any components
  associated with the MCLR pin". Four parts inside a 6 mm radius is the
  tightest cluster on the board; lay it out first, before anything that is
  merely convenient. (This said "before the escape header, not after" — in the
  event the cluster won and the header went, 5.4.)
- **The oscillator circuit within 12 mm of pins 9/10**, on the same side of the
  board as U1, with C1 and C2 next to Y1 itself — 2.6.
- **A grounded copper pour around the oscillator**, routed directly to the MCU
  ground pin, with **no signal or power traces run inside it** — 2.6. This is
  stronger than "do not let the pour split the ground under the crystal": the
  pour is a deliberate guard, not a leftover.
- **Nothing on the bottom layer underneath the crystal** — 2.6 says so in as
  many words for a two-sided board, and both of ours are.
- **Keep fast or noisy signals away from pins next to the oscillator** — 2.6
  again. In practice that means the CAN pair and the ICSP lines.
- U2 between U1 and the connectors — CANH/CANL should be short and never cross
  the crystal.
- J1/J2 on the same long edge so the harness leaves in one direction; the vent
  has no room for cables on two sides.
- D1/D2/JP1 grouped where they are visible without disassembling anything, and
  JP2 somewhere a finger and a pair of pliers can reach — it comes out for every
  programming session.
- **Keep parts and copper out of a 7 mm circle around each of H1–H4.** A nylon
  M3 standoff has a 6 mm head and it has to sit flat.

### 5.2a Placement as built — done

Parts are placed and `tools/check-placement.py` is clean. U1 sits across the
middle at rot 270, which puts **pins 1–14 along its top edge running right to
left** and pins 15–28 along the bottom. Everything else follows from that:

| U1 pin | Faces  | What went next to it |
| --- | --- | --- |
| 1 MCLR | top right | R6, R1, C8, JP2 in the top-right corner |
| 6 VCAP | top | C7 on B.Cu, under the package |
| 9/10 OSC | top | Y1 mirrored, C1 and C2 standing either side  |
| 20 VDD | bottom | C3 directly below |
| 23/24 CAN | bottom | U2 below right, then J1/J2 |
| 27/28 ICSP | bottom | J3 below left |

J1/J2 sit on the bottom edge, cables leaving downwards. D1/D2 and their
resistors run down the left edge where they can be seen. The right-hand column
held J4 and now holds most of the MCLR network instead.

Measured against the datasheet:

| Rule | Constraint | Measured |
| --- | --- | --- |
| 2.4 | C7 → U1.6 ≤ 6 mm | **2.25 mm**, on B.Cu |
| 2.2.1 | C3 → U1.20 ≤ 6 mm | **5.67 mm** |
| 2.2.1 | C4 → U2.3 ≤ 6 mm | **5.68 mm** |
| 2.2.1 | C5 → U2.5 ≤ 6 mm | **4.49 mm** |
| 2.6 | Y1/C1/C2 ≤ 12 mm | **5.35 / 9.79 / 6.98 mm** from the pin each is on |

**Two things about the wording are worth keeping.** §2.2.1 and §2.4 limit the
*trace length from the pin to the capacitor*; §2.3 and §2.6 talk about where the
*components are placed*. Those are not the same measurement and the difference
decides whether this board passes, so `check-placement.py` keeps them apart.
§2.6 also says "close to the **respective** oscillator pins", so C1 is measured
against OSC1 and C2 against OSC2 — the pins they are actually on.

**Where §2.3 is not met, and why.** It asks for R1, R6, C8 and JP2 all inside a
6 mm circle centred on pin 1. Pin 1 is a corner pin, so about three quarters of
that circle is free — roughly 85 mm² — and the four parts are 71 mm² of
courtyard between them. They do not fit, and no choice of footprint changes
that: this is an area problem, not a lead-pitch problem.

What was done instead is to make all four hug the pin rather than get one of
them fully inside. The arrangement was found by search (`mclr_opt.py`, a
throwaway), minimising the worst far corner over every legal position and
rotation:

| | nearest edge | farthest corner |
| --- | --- | --- |
| C8  | 1.66 mm | 7.50 mm |
| JP2 | 1.88 mm | 8.67 mm |
| R1  | 2.89 mm | 8.91 mm |
| R6  | 2.46 mm | 7.63 mm |

Every part is within 3 mm of the pin at its nearest edge, and the far corners
are bodies extending outward, not connections — the pin sees the near end.

**R1 is then moved 1.20 mm further out, on purpose.** The search
above optimised for distance to the pin and produced an arrangement where R1's
courtyard and C8's touched — 0.03 mm — with R1 pad 2 and C8 pad 1 2.66 mm apart,
1.06 mm of bare board between the copper. Those two pads are `MCLR_RC` and
`MCLR_C`: the two ends of JP2. A solder bridge there would tie the jumper
closed permanently, which is the one failure the jumper exists to prevent, and
it would look like a working board until the first attempt to program it.

Moving R1 west by 1.20 mm opens that gap to 2.26 mm of bare board (courtyards
1.23 mm apart) and costs about 0.9 mm of extra track from R1 to the MCLR node.
R1 is the 10 kΩ static pull-up — the least length-sensitive part of Figure 2-2 —
so that is the right part to spend the distance on. The move was sized by the
nearest-edge rule, not by eye: 1.20 mm is what keeps R1 at 2.89 mm, inside the
3 mm assertion with a little margin. `ALLOW["2.3 R1"]` went from 8.5 to 9.0 to
match, which is where JP2 already sits.

The two tracks that reach R1 were re-laid for it. +5V arrives on B.Cu along
y = 61.4 and would otherwise step down into pad 1 right where pad 2 sits, so
the
step became a longer run west and one 45° diagonal; `MCLR_RC` gained a 45°
diagonal from the new pad 2 up to the existing vertical at x = 92.8. DRC is
clean and there are no unconnected items.

An earlier arrangement had R6 wholly inside at 5.94 mm but C8 out at 10.68 mm.
That was worse: R6 fitting was an accident of it being small, and it left the
reset capacitor — the part §2.3's own Figure 2-2 note is about — furthest away.
The room to improve came from removing J4, whose column was inside the circle
(see 5.4).

`tools/check-placement.py` records the tolerated far corners in `ALLOW` with
their reasons and, more to the point, asserts that every nearest edge stays
within 3 mm. That second check is the one carrying weight. Do not widen either
to make a red run green.

**Standing resistors.** R1–R6 are `R_Axial_DIN0207_L6.3mm_D2.5mm_P2.54mm_Vertical`
and C8 is the 2.50 mm disc, rather than the 10.16 mm horizontal parts — body
upright, leads bent to the narrowest spacing. It is what gets R6 inside the
circle at all: upright, a resistor reaches 3.95 mm from its first pad against
11.36 mm lying down.

**C7 is turned across the package, not along it.** Lying along the pin row its
ground pad shorted pin 5; in the empty channel between the two rows it clears
both rows by 0.79 mm and still lands 2.25 mm from pin 6.

### 5.3 Net classes

| Class | Nets | Track width | Clearance |
| --- | --- | --- | --- |
| Default | signals | 0.25 mm | 0.20 mm |
| Power | +5V, SGND | 0.80 mm | 0.20 mm |
| CAN | CANH, CANL | 0.40 mm | 0.20 mm |

Route CANH/CANL as a pair, side by side, equal length, no stubs beyond the DNF
R5 pads. Pour SGND on both layers and stitch the pours with vias, but do not
let the pour split the ground under the crystal.

**Done.** The three classes are in `canfuel.kicad_pro`, assigned by netclass
pattern: `+5V` and `SGND` to Power, `CANH` and `CANL` to CAN, everything else
Default. Via sizes stay at KiCad's 0.6/0.3 mm for all three — the table above
sets track width and clearance only, and 0.3 mm drill is inside every fab
house's standard process. That is a manufacturing choice, not a datasheet
number, and nothing in this repository depends on it.

**Routing plan for the layer split**, which falls out of the placement:

- Everything leaving U1's **top row goes down into the channel between the two
  pin rows first**, then out sideways. That keeps the area above the top row
  clear for the oscillator's grounded guard, which §2.6 requires be free of
  signal and power traces.
- **Nothing on B.Cu under the crystal.** §2.6 says so in as many words for a
  two-sided board. The grounded pour there is the guard the same section asks
  for, and is not what "traces" means.

Both are given to the router as keep-out rectangles and re-checked afterwards
by `check-placement.py`, so they cannot quietly rot.

**Done, 0 unconnected items.** Routing was done by a throwaway grid router
(A* per connection over both layers, 0.2 mm grid) rather than by hand — thirty
nets of hand-written waypoints is a lot of arithmetic to get wrong. Two things
it taught, worth knowing if it is ever run again:

- **Net order decides whether it finishes.** Oscillator and VCAP first, then
  the rest alphabetically, routed 32 of 39 with J4 still fitted. Longest-first
  managed 25 and +5V-last managed 27: the 0.8 mm +5V net becomes a wall the
  thin signals cannot cross if it goes early, and cannot reach its own thirteen
  pads if it goes late.
- **A via is 0.6 mm of copper on both layers, not a point.** Treating it as a
  point produced three clearance violations DRC caught afterwards.

### 5.4 The escape hatch was removed — measured, not argued

J4 was a 2×8 header bringing out all 14 unused I/O pins plus power, so a design
error could be patched with a wire rather than a new board. It was fitted, and
it was then **taken off again.** Do not put it back without reading
this.

**What it cost, measured.** Routing the board with and without it, same router,
same placement, same ordering:

| | with J4 | without J4 |
| --- | --- | --- |
| connections to route | 39 | 25 |
| **left unroutable** | **8** | **0** |
| DRC | incomplete | **0 violations** |

**The part that settles it is which connections failed.** Five of the eight
were not escape signals at all:

- `LED_PWR` and `LED_CAN` — both status LEDs
- `PGD`, `PGC` and `~{MCLR}` — the entire ICSP header

J4 does not only occupy its own area. Its fourteen signals congest the channel
between U1's two pin rows, which is the only way across the board, and the ICSP
and LED nets are what get starved. A header whose whole purpose is to rescue a
design error was preventing the chip from being programmed — which is the
design error it would have had to rescue.

**What replaces it.** Nothing on the board. U1's fourteen unused pins carry
no-connect flags in the schematic. If a patch is ever needed, it goes onto the
**PDIP socket pins from underneath** — they are through-hole and accessible, so
the escape route survives without the header. That was the maintainer's call
and it is a good one: the socket was always the real escape hatch.

**What the space bought.** J4 sat in the right-hand column, which lies inside
the 6 mm circle DS39977C §2.3 draws around U1 pin 1 — so it was also the reason
the MCLR cluster could not be tightened. With it gone the cluster was re-placed
by search (see 5.2a) and the worst far corner fell from 10.68 mm to 8.67 mm,
with every one of the four parts now within 2.5 mm of the pin at its nearest
edge.

The `RA1-RA3,RA5` / `2mA MAX` silkscreen legend went with it; it warned about
the weak port A pins on a header that no longer exists.

Value fields moved to F.Fab in the same pass. At this density the stock field
positions collided with each other and sat over pads; the references are what
a hand-assembler needs on the silkscreen, and the values are in the BOM and on
the fab drawing already.

That left the front silkscreen carrying reference designators and footprint
outlines and nothing else — which is right for every part but one. R5's `120R
DNF` warning went with the values, and stayed missing until the 6 pre-order
check caught it. It is now a board-level text, not a footprint field, so it
cannot be swept up by a change to how fields are placed.

### 5.5 DRC

```
kicad-cli pcb drc --exit-code-violations canfuel/canfuel.kicad_pcb
python tools/check-placement.py
```

**Both are clean: 0 violations, 0 unconnected items.** The board is routed on
two layers with SGND poured on both and stitched through the through-hole pads.

**DRC on its own is not enough, for the same reason ERC was not.** A decoupling
capacitor 40 mm from its pin is a perfectly legal board — it is just a broken
one, and DRC will pass it without complaint. `check-placement.py` is the
board's equivalent of `check-netlist.py`: it re-measures the four distance
rules of 5.2, the mounting-hole keepouts and the §2.6 oscillator guard, and
carries the tolerated §2.3 shortfalls with their reasons so an intentional
deviation never reads as a regression.

**Pads connect to the pours through thermal reliefs** — 0.6 mm spokes, 0.3 mm
gap. The board is hand soldered, and a through-hole ground pin tied straight
into a plane sinks heat faster than an iron replaces it; cold joints on ground
are the usual result. The first attempt used 0.8 mm spokes and two pads came
out with a single spoke each, which DRC flags as `starved_thermal`; narrowing
the spokes let the rest through.

Then, separately from either, do the checks a tool cannot do: run the 3D viewer and confirm the socket, the electrolytic and both
Micro-Fit bodies do not collide, and print the board 1:1 on paper and drop the
real connectors onto it.

**Definition of done:** DRC clean, committed, CI green.

---

## 6. Fabrication outputs — done

Generated into `canfuel/fab/` and **committed** — for an ordered board it must
be possible to recover exactly what was sent.

```
fab/gerbers/    9 gerbers, canfuel-PTH.drl, canfuel-NPTH.drl,
                their two drill maps, canfuel-job.gbrjob
fab/canfuel-bom.csv
fab/canfuel-cpl.csv
```

These are the commands as run, not an outline. Every flag beyond the bare
export is here because the default was wrong for this board:

```
kicad-cli pcb export gerbers --output canfuel/fab/gerbers \
  --layers "F.Cu,B.Cu,F.Paste,B.Paste,F.SilkS,B.SilkS,F.Mask,B.Mask,Edge.Cuts" \
  --check-zones canfuel/canfuel.kicad_pcb
kicad-cli pcb export drill --output canfuel/fab/gerbers \
  --excellon-separate-th --generate-map --map-format gerberx2 \
  canfuel/canfuel.kicad_pcb
kicad-cli sch export bom --output canfuel/fab/canfuel-bom.csv \
  --group-by "Value,Footprint" canfuel/canfuel.kicad_sch
kicad-cli pcb export pos --output canfuel/fab/canfuel-cpl.csv \
  --format csv --units mm --side both --exclude-dnp canfuel/canfuel.kicad_pcb
```

- `--layers` is mandatory in practice: `export gerbers` plots nothing useful
  without it. Both paste layers are included even though only C7 is SMD.
- `--check-zones` refills the pours before plotting, so a stale fill cannot be
  what gets sent. It changes the output, never the board file.
- `--format csv --units mm` on `export pos`: the default is ASCII in inches,
  which would have produced a file named `.csv` that is not one.
- `--exclude-dnp` keeps R5 out of the CPL. It is the one part on the board that
  must not be fitted; a placement file listing it is worse than no file.
- `--excellon-separate-th` splits the drilling into `canfuel-PTH.drl`
  (`TF.FileFunction,Plated,1,2,PTH`, tools 0.30/0.80/0.90/1.00/1.02) and
  `canfuel-NPTH.drl` (`NonPlated,1,2,NPTH`, tools 3.00 and 3.20). A single
  merged `MixedPlating` file was produced first and tags every tool correctly,
  so it loses nothing on paper — but the peg holes of 3.7 fail if they are
  plated by mistake, and two files whose names say what they are cannot be
  misread. That is worth more than one fewer attachment.

The CPL is generated for completeness only — every part here is through-hole
and hand-soldered, so no assembly house will use it.

**Both pre-order checks pass, and one of them needed a fix first.**

- R5 is absent from `canfuel-bom.csv` (23 rows against 24 parts) and from
  `canfuel-cpl.csv`. It carries `in_bom no` and `dnp yes` on the sheet.
- The two **DIP sockets are absent from `canfuel-bom.csv` as well**, and cannot
  be otherwise — they have no schematic symbol, so KiCad has nothing to emit.
  They are in the parts table of §2 as rows with no reference. Anyone
  populating from the CSV alone solders U1 and U2 straight into the board and
  loses the escape hatch this design leans on;
  `canfuel/docs/firmware/install.md` step 5 now says so out loud.
- The silk layer **did not** carry the `120R DNF` legend of 3.3 until now. The
  board had no board-level text at all: value fields went to F.Fab in the 5.4
  pass and the R5 footprint only ever put its *reference* on F.SilkS, so the
  silk read `R5` and nothing else. A `120R DNF` `gr_text` was added at
  (93.2, 91.5), F.SilkS — at the 1.0 mm height of 6.1 its extent is
  x 89.31..97.09, y 90.65..92.35, which is 0.45 mm clear of R5 pad 2 and
  0.41 mm clear of the 3.5 mm keepout
  around H4. DRC stays at 0 violations and 0 warnings with `silk_overlap`,
  `silk_over_copper` and `silk_edge_clearance` all enabled, and the plotted
  strokes are in `canfuel-F_Silkscreen.gto`.

  This is exactly why the check is written down as a check. `120R DNF` is the
  only thing on the board that tells an assembler not to fit a part that has a
  footprint, pads and a value — and it was the one legend nothing else would
  have caught.

### 6.0 What to send a fab house

A pooled two-layer service is enough for this board: **Cu 35/35 µm, 1.5 mm,
HAL or ENIG, solder mask both sides, silkscreen one side, single pieces milled
out, min track/gap class ≥150 µm**. No assembly stencil — C7 is the only SMD
part and it is hand-soldered.

Upload both `Gerbers.zip` and `Odb.zip` if the house takes ODB++; they are
generated from the same board, so they cannot disagree, and ODB++ is what most
CAM departments prefer.

⚠ **Send a `README.txt` with the package**, because configurators rarely have a
comment field and it has to say four things:

- the PTH diameters are **finished** sizes, not drill sizes;
- the NPTH ones are **not plated**;
- **why** the 3.00 mm peg holes in particular must not be plated (3.7);
- that **R5 is deliberately unpopulated**, so its `120R DNF` legend is not read
  as a data error.

**Order one more board than you intend to populate.** The board is the long-lead
item; every other part arrives in days.

### 6.1 printed.cz — capability check

<https://printed.cz/vyroba-dps/>, the first fab house considered. Their
published limits against this board, measured from `canfuel.kicad_pcb`:

| Parameter | printed.cz | canfuel | |
| --- | --- | --- | --- |
| layers | 1–12 | 2 | ok |
| max size | 600 × 600 mm | 55 × 45 mm | ok |
| thickness | 0.2–3.2 mm | 1.6 mm | ok |
| outer copper | 18/35/70/105 µm | 35 µm | ok |
| min track | 0.075 mm (rec. 0.15) | 0.25 mm | ok |
| min spacing | 0.075 mm (rec. 0.15) | 0.20 mm | ok |
| drill range | 0.2–6.3 mm | 0.30–3.20 mm | ok |
| min annular ring | 0.15 mm | 0.15 mm via, 0.24 mm pads | **at the limit** |
| finish | HASL Pb-free, gold, OSP | HASL | ok |
| mask / legend | green… / white, black, yellow | green + white | ok |
| **min text height** | **1 mm** | **was 0.80 mm** | **failed** |
| **min legend stroke** | **0.15 mm** | **was 0.12 mm** | **failed** |
| min order | 1 pc | 1 pc | ok |
| e-test, AOI | free | — | ok |

Track and spacing are not merely inside the limit, they are above the value
the page *recommends* — this board asks for the cheapest process class they
run. Two things are worth recording:

**The legend failed, on every single text.** All 25 silkscreen items — 24
reference designators and the `120R DNF` of 3.3 — were 0.80 mm high with a
0.12 mm stroke, under both minimums. They are now 1.0 mm / 0.15 mm, which is
also what `silk_text_size_h/v` and `silk_text_thickness` in the project
defaults have always said; only the placed items disagreed. Nothing had to
move: DRC reports 0 violations with `silk_overlap`, `silk_over_copper` and
`silk_edge_clearance` raised to `error`, and only the two silkscreen gerbers
changed — copper, mask, paste, drill, edge and the `.gbrjob` are byte-identical
apart from their timestamp line.

**Our own DRC could not have caught it, and now can.** `min_text_height` was
0.8 and `min_text_thickness` 0.08 — looser than the process, so the board
passed its own rules while failing the fab's. Both are now set to the
printed.cz values.

That alone would still have been useless. `text_height` and `text_thickness`
ship as **warnings**, and `kicad-cli pcb drc --exit-code-violations` returns 0
on warnings: with the tightened numbers and the old 0.80 mm text, the report
listed all 50 violations and the command still **exited 0**. That was measured,
not assumed. Both severities are now `error`, which was measured too — the same
board and rules exit 5. A check that cannot fail is not a check; this
repository has already been bitten by that twice, in CI.

`silk_overlap`, `silk_over_copper` and `silk_edge_clearance` are still
warnings and therefore still cannot fail a run. The board is clean under all
three at `error` severity, so promoting them costs nothing — left as a
deliberate open choice rather than changed unasked.

**The via annular ring is exactly at their stated minimum.** 0.15 mm, from a
0.60 mm pad on a 0.30 mm drill, on six vias. It is allowed and they publish it
as manufacturable, but there is no margin. Component pads are 0.24 mm and up,
so it is the vias alone. If they push back, a 0.70 mm via pad gives 0.20 mm;
ask before changing anything.

**Drill diameters must be declared, and the common default is the dangerous
one.** The handbook says outright: *"Pokud nebude žádná poznámka, výrobce DPS
předpokládá, že jde o průměry výsledné"* — with no note, the numbers are read
as finished holes, and a plated hole loses about 0.1 mm to the plating. That
default happens to be what this board wants, and it is still stated explicitly
in the enquiry, because the one hole that cannot absorb the error is J1/J2 at
1.02 mm (3.7). The wording to send:

> Průměry prokovených otvorů (`canfuel-PTH.drl`: 0,30 / 0,80 / 0,90 / 1,00 /
> 1,02 mm) jsou **výsledné** rozměry po prokovení. Otvory v
> `canfuel-NPTH.drl` (3,00 a 3,20 mm) jsou **neprokovené**, vrtaný rozměr =
> výsledný.

**Their standard plated-hole tolerance is wider than Molex's, and it still
passes.** A typical pooled service quotes ±0.08 mm standard (±0.05 mm on
request) against the
drawing's ±0.05 mm, so the worst case is a 0.94 mm hole where Molex allows
0.97 mm. It does not matter: the pin is 0.64 mm square, diagonal 0.905 mm, so
even 0.94 mm leaves 0.035 mm of clearance. **Do not pay for the tighter
tolerance class.** The NPTH tolerance is ±0.05 mm, which matches the peg hole's
band exactly, so a 3.00 mm nominal lands inside Molex's 2.95–3.05 at both
extremes.

**The board is 1.5 mm, not 1.6 mm, and it was changed to match the order.**
Pooled services sell fixed stack-ups and the two-layer ones are generally
1.5 mm; the chosen preset is *2V Cu 35/35 µm, 1,5 mm, LF HAL, 2x zelená NM, 1x
bílý potisk, Tg 135 °C*. Nothing on this board depends on the 0.1 mm: the via
aspect ratio goes from 1:5.3 to 1:5.0 against a 1:10 limit, lead-free HAL wants
0.8–2.5 mm, and SD-43045-001 *recommends* 1.57 mm for the Micro-Fit — 1.5 mm is
0.07 mm under it, which is the safe direction for a snap-in peg because the
barb protrudes further below the board.

What did matter is that `canfuel-job.gbrjob` declared `BoardThickness: 1.6`.
Ordering 1.5 mm while shipping a job file that says 1.6 mm is the kind of
contradiction a CAM operator either queries or silently resolves the wrong way,
and it defeats the whole reason `fab/` is committed. So `(general (thickness))`
is 1.5 and the core is 1.41 mm, and the outputs were regenerated. **The number
lives in `(general (thickness))`, not in the stackup sum** — editing only the
core left `GetBoardThickness()` reporting 1.600, which is how the second edit
was found.

**Copper is 35 µm and the reason is not current.** An 18 µm preset was offered
and is cheaper. At 18 µm the 0.80 mm power track still carries about 1.26 A by
IPC-2221 for a 10 °C rise, against this board's 77 mA worst-case peak, so
electrically either would do. It is 35 µm because the board file's stackup and
the `.gbrjob` both declare 35 µm, and a delivered board that disagrees with its
own documentation is the thing `fab/` exists to prevent.

**No assembly stencil.** The POOL configurator offers one and it is the wrong
purchase twice over. It is offered *Pro vrchní stranu*, and `F.Paste` has zero
drawing commands — the top side has no SMD pads at all, so that stencil would
be a blank sheet of steel. Even a bottom one would cover `B.Paste`'s two
flashes, which are C7's pads, on a board that is hand-soldered throughout.

**No surcharges apply.** Construction class 7 (+10 %) starts at 150 µm track or
gap and this board is at 200 µm; the drill-density surcharge starts at 1001
holes/dm² and this board has 97 holes on 0.2475 dm², or 392/dm². Board
thickness 1.6 mm and lead-free HAL are both base price.

**Not published on their page, so ask:** whether a ZIP of the gerbers is
enough and whether Protel extensions are fine, copper-to-edge clearance (this
board holds 0.30 mm against their 0.200 mm for milled outlines), lead times and
price. ODB++ is their preferred format and `kicad-cli pcb export odb` produces
it, so it is worth offering.

---

## 7. Purchase list

Only now, and derived from `fab/canfuel-bom.csv` — not typed out by hand.
Cross-check against `bom-purchase.pdf`.

- **On the board:** everything in `fab/canfuel-bom.csv`, **plus two DIP
  sockets** — narrow 7.62 mm DIP-28 for U1 and DIP-8 for U2. The sockets have
  no schematic symbol, so no generated BOM can ever list them; miss them and U1
  and U2 get soldered straight into the board.
- **Not on the board, but needed:** SIBA 179120.0.2 fuse (200 mA, time-lag T,
  5 × 20) and inline holder K23411, for the harness. These are not in
  `fab/canfuel-bom.csv` and never will be — the BOM comes from the schematic
  and the fuse is not on it. Buy a spare fuse; a blown one behind the dash is
  worth having a second of. See 9.2.

**Two of those parts are specified rather than merely valued**, and a
substitution that ignores this is the kind that works on the bench and fails
later:

- **Y1's load capacitance must be stated by whoever sells it.** This one is
  20 pF, and that number is what sets C1/C2 to 33 pF in 3.2. A crystal with an
  unknown CL cannot be checked against that and so cannot be used, whatever it
  costs.
- **C6 must carry a temperature and load-life rating**, because an electrolytic's
  oxide layer is a consumable and the argument immediately below is what makes
  this one comfortable. A part sold without those figures cannot be held to it.

*(Sorting parts by whether they were already to hand or had to be bought says
nothing a second builder can act on. What matters is what a part has to
satisfy.)*

**C6 is a 105 °C part and needs no second thought.** It is GME 127-040, a
Hitano `EXR` 10 µF 16 V in 5 × 11 — `hitano-exr-datasheet.pdf`, which gives
−40 to +105 °C and a 2000 hour load life at 105 °C with rated ripple for the
5 mm case. Halving the temperature stress doubles that, so at the 50–60 °C a
closed vent reaches in summer it is tens of thousands of powered hours, and the
board is only powered while the display is. It carries no ripple worth the name
either — total draw is under 30 mA. This was the last open question on the
board and it is closed.

That same datasheet settles §3.5 from the other direction. Its case table gives
this exact part an impedance of **4.70 Ω at 100 kHz**, against the 5 Ω ceiling
DS39977C Table 31-4 puts on the VCAP capacitor. Had the six of them bought for
C6 been pressed into service on pin 6 as well — which is exactly the mistake
the shape of the order invited — the part would have sat at 94 % of the limit
with nothing left for tolerance or temperature.

---

## 8. Committing work on a board

**One rule, and it outlives this board:** every commit leaves CI green. If the
schematic needs several passes, that is fine — but never commit one that fails
ERC, because then a red CI run stops meaning anything.

The commit-by-commit account of how this board was built is git history and is
not duplicated here.

---

## 9. Open questions

**There are none left.** The one row this table held was the 4-pin
connector for the car side of the harness, and that is settled: the connector
exists and is fitted, so the loom is a re-crimp onto longer wires rather than a
choice to make. C6's temperature class was the other and is settled in section
7: it is a 105 °C part.

Every part is bought, the harness fuse and holder included. **Nothing blocks
the layout, and nothing blocks fabrication either.** The enclosure blocked the
layout once, and there is no longer going to be one.

### 9.1 The enclosure was dropped, and why

It bought nothing here. Everything around the board in the vent is plastic, so
there is no metal to short against; the vent is closed off by a flap, so no
air, no dust worth the name and no water; and the board is invisible either
way. That leaves mechanical retention, which a box is a poor way to buy.

The measurement made it worse rather than better. The available space was only
ever an estimate — the MFD15 sits in the way and the depth cannot be measured
around it — and the closest off-the-shelf candidate, a Hammond 1550Q at
60 × 55 × 30.10 mm, came out exactly at the estimate on two axes and 0.1 mm
over on the third. Its 3 mm die-cast walls would also have forced corner
notches in the board, added an isolation and grounding decision that a plastic
box does not, and required a slot filed through cast aluminium for the
Micro-Fit connectors.

Dropping it inverts the risk section 9 would otherwise carry. The M3 holes no
longer have to hit anything, so they stopped being the thing that could force a
respin and became cheap insurance instead: any later mounting scheme is
designed around them.

**Mounting, as decided:** four nylon M3 standoffs in the holes, their feet
stuck to the floor of the vent with automotive-grade double-sided tape (3M VHB
or equivalent). Standoffs rather than tape straight onto the board because the
through-hole solder joints must not bear on anything, and VHB rather than
ordinary foam tape because a dashboard reaches 50–60 °C in summer and cheap
adhesive lets go there.

**Rejected:** wrapping the board in PVC or Tesa tape. At dashboard temperatures
the adhesive creeps, ends up smeared across the board, collects dust, works its
way into the sockets and makes any future repair miserable — and the insulation
it provides guards against metal that is not there.

Resolved earlier: the core supply (3.5 — no ENVREG, 10 µF on pin 6), the LED
pin assignment (RC0/RC1, see 3.6) and the escape header — which at the time
resolved as "2×8, it goes on", and was then removed once routing
put a number on what it cost (5.4).

### 9.2 The 5 V feed is fused — in the harness, not on the board

The board takes 5 V straight from the display and has no protection of its own.
A short anywhere on it — a bridged solder joint, a failed electrolytic — is
therefore a short across the MFD15's 5 V rail. Adding a fuse closes that.

**It goes in the loom, not on the PCB, and that is a measured decision.** The
largest free rectangle left on the board is 12.2 × 15.2 mm, at x 92–104.5,
y 72–87.5; a 5 × 20 mm holder lying flat needs about 24 × 7 mm and there is no
rectangle that size anywhere on the board. The alternatives were a vertical
holder standing ~25 mm tall — against a vent depth that has never been
measurable, because the MFD15 is in the way — or soldering the fuse down, which
gives up the one thing a cartridge fuse is for. In the loom it costs the board
nothing: the schematic, the PCB and all four checks are untouched.

Access is the reason a cartridge fuse beats a resettable PTC here, and it comes
from the car, not a datasheet: pulling the MFD15 out of the vent exposes this
part of the loom, so replacing a blown fuse does not mean dismantling the
dashboard.

**The parts.** SIBA **179120.0.2** — 200 mA, 250 V, 5 × 20 mm, glass, time-lag
T to IEC 60127-2/3 (`siba-179120-fuse-datasheet.pdf`, doc G79120-30 Rev. 0) —
in inline cable holder **K23411** (`fuse-holder-5x20-datasheet.pdf`), which
takes a 5.2 × 20 mm fuse and comes with 200 mm of lead. Its body is about
46 mm long and 10.5 mm across, so it needs a straight run of loom that length
and it must not be buried where it cannot be unscrewed.

That drawing is the whole of the holder's datasheet: it carries no ratings. The
6.3 A / 250 V AC figure is from the GME product page, which is a shop listing
and not a manufacturer document — recorded here as such. It does not matter
much either way, since the fuse in it is rated 200 mA and the circuit runs at
5 V.

**Why 200 mA, from the datasheet's own table.** The row for 200 mA gives a
voltage drop of **500 mV** at rated current, 0.3 W dissipation at 1.5 In and a
melting integral of **0.7 A²s**. Both numbers decide something:

- *The drop.* 500 mV at 200 mA is 2.5 Ω while the element is hot, and that is
  not negligible against the 0.51 V of headroom between the 5.01 V measured at
  C6/C12 and the 4.5 V minimum DS20005167C §2.2 puts on the MCP2562's VDD. It
  is survivable because **C6 is downstream of the fuse**: the 45–70 mA the
  transceiver draws during dominant bits comes out of the ~10.3 µF of C6 plus
  C3/C4/C5, and the fuse only ever sees the average, which is under 30 mA.
  At 30 mA even the hot resistance gives 75 mV. Had the bulk capacitor been
  left on the display side of the fuse, this would not work.

  **C7 is not part of that 10.3 µF**, though it sits downstream of the fuse
  too. It is on VDDCORE, behind the on-chip regulator, and a series pass
  regulator does not deliver charge backwards into its own input — so it holds
  the core rail up and contributes nothing to the transceiver's dominant-bit
  current. `components.md` §4 has the reasoning.
- *The melting integral.* Charging C6, C3/C4/C5 and C7 — the last of them
  through the regulator — is about 20 µF from 5 V through a loom of well under
  an ohm, an I²t of the order of 10⁻³ A²s, three orders below 0.7 A²s. Inrush
  cannot nuisance-blow it, which is what the time-lag characteristic was chosen
  for in the first place.

**Why it protects what it is meant to.** The display's limit is 0.5 A. The
fusing-time limits in the same datasheet, for the 125 mA – 6.3 A group:

| | 1.5 In = 0.30 A | 2.1 In = 0.42 A | 2.75 In = 0.55 A | 4 In = 0.80 A | 10 In = 2.0 A |
| --- | --- | --- | --- | --- | --- |
| min | 1 h | 600 ms | 150 ms | 20 ms | — |
| max | — | 2 min | 10 s | 3 s | 300 ms |

Any fault heavy enough to exceed the display's 0.5 A opens the fuse inside
10 s, and a hard short inside 300 ms. Normal running is 30 mA, 15 % of rating,
nowhere near the 1 hour it is guaranteed not to open at 0.30 A. The band it
does not cover is 0.30–0.42 A sustained — and that is below the display's limit
anyway, so nothing there needs covering.

**What it does not protect.** The fuse sits at the vent end of the loom, where
it is reachable. The run from plug C to the fuse is therefore unfused. That is
deliberate: the fault this exists for is on the board, and that section of loom
lies inside the dashboard without movement. Moving the fuse to the plug C end
would cover the cable too, at the price of the access that made a cartridge
fuse the right choice.

`harness.md` section B has the wiring steps.

---

## 10. What has actually been read out of the datasheets

The sourcing rule in `CLAUDE.md` is only worth anything if it is possible to
tell which numbers were checked and which were inherited. This is the checked
list, as of the datasheet re-review.

**DS39977C — PIC18F25K80**

| Section / page | What it settles |
| --- | --- |
| page 6 | The 28-pin SSOP/SPDIP/SOIC pinout, every pin in 4.2. Pin 6 is VDDCORE/VCAP, there is no RA4, CANTX/CANRX are on RB2/RB3 and again on RC6/RC7 |
| 2.1, Fig 2-1 | The pins that must always be connected; AVDD/AVSS exist only on the larger packages |
| 2.2.1 | 100 nF ceramic low-ESR on every supply pin pair, within 6 mm, same side of the board |
| 2.2.2 | Tank capacitor 4.7–47 µF where power traces exceed six inches — C6 |
| 2.3, Fig 2-2 | The MCLR network of 4.3a: R1 ≤ 10 kΩ, R2 ≤ 470 Ω, C1 on a jumper, all within 6 mm of the pin |
| 2.4, Table 2-1 | VCAP: 10 µF low-ESR (< 5 Ω), ceramic or tantalum, never to VDD, track under 6 mm; the 0.1 µF figure belongs to the LF part; Table 2-1 names the fitted GRM32DR71C106KA01L |
| 2.5 | No pull-ups, series diodes or capacitors on PGC/PGD; optional ≤ 100 Ω series resistor for ESD |
| 2.6 | Oscillator placement: 12 mm, load caps at the crystal, grounded pour with nothing routed inside it, nothing on the far side under the crystal |
| 2.7 | Unused I/O driven low as outputs, or 1–10 kΩ to VSS |
| 3.5, Table 3-3 | Crystal capacitor guidance, and note 3 deferring to the crystal manufacturer; note 2 on Rs for low drive level |
| page 541 | Absolute Maximum Ratings — the 2 mA on PORTA<5:0> behind 3.6 |
| D001 | VDD 1.8–5.5 V for F devices |
| D080, D090 | VOL/VOH, and the contradiction with page 541 discussed in 3.6 |
| Table 31-4 | CEFC 4.7 µF min, 10 µF typ, low-ESR |

**DS20005167C — MCP2561/2**

| Section | What it settles |
| --- | --- |
| page 1 | MCP2562 DIP-8 pinout — the table in 3.1; the MCP2561's pin 5 is SPLIT, ours is VIO |
| 1.1.1, 1.1.2, Table 1-1 | STBY low is Normal, high is Standby |
| 1.7.9 | STBY has an internal MOS pull-up, typ 660 kΩ at 5 V — floating means Standby |
| 1.7.6 | VIO supplies TXD, RXD and STBY |
| Fig 1-2 | Application circuit: 0.1 µF on VDD and on VIO |
| 2.2 | VDD 4.5–5.5 V, VIO 1.8–5.5 V |
| Abs max | CANH/CANL −58 V to +58 V, transients −150 V to +100 V, ±8 kV IEC 61000-4-2 |

**Crystal datasheet**

| What | Value |
| --- | --- |
| Loading capacitance | 20 pF standard, 8–33 pF available — behind 3.2 |
| Part number example | `FTX16.000M20S-30/30B`: 16.000 MHz, 20 pF, HC49/S |
| Drive level | 100 µW typical, 500 µW max |
| ESR, 14–40 MHz | 30 Ω max |
| Dimensions | 11.40 × 4.80 max, H ≤ 3.5 mm, leads 4.88 ± 0.2 mm |

**Hitano EXR — C6**

| What | Value |
| --- | --- |
| Temperature range | −40 to +105 °C |
| Load life, 5 mm case | 2000 h at 105 °C with rated ripple |
| Shelf life | 1000 h at 105 °C, no voltage applied |
| 10 µF 16 V, 5 × 11 | impedance 4.70 Ω at 100 kHz, ripple 74 mA rms |

That last row matters for 5.2: the KiCad footprint is
`Crystal:Crystal_HC49-U_Vertical`, whose pads are 4.88 mm apart and therefore
correct, but whose 3D model is the taller HC-49/U can. The real part is the
shorter /US. The 3D check in 5.5 will show it standing taller than it is —
that is the model, not a clearance problem.

**Not settled by any datasheet, and deliberately so:** the display's connector
pinout (C6/C12/C7/C8) and the fact that the car's bus is already terminated at
both ends. Both were measured on the car. They are noted as measured wherever
they appear.

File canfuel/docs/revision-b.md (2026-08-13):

# Ideas for a revision B

**There is no revision B, and nothing here is scheduled.** The board is
finished, ordered and frozen at commit `c06e710`; `CLAUDE.md` says not to touch
the design while the order is in flight and that still holds. This file is
where an idea goes that is worth keeping but must not turn into an edit.

The rule from `CLAUDE.md` applies here as everywhere: every number below cites
its datasheet, and anything that is a judgement rather than a specification
says so.

---

## B1 — Hold-up supply and shutdown detection

**What it would buy: the converter would lose nothing at all when the ignition
is switched off.** Today it loses up to twenty seconds of accumulated fuel and
distance, every single time.

### The problem, which is a firmware problem the board could solve

The firmware keeps its trip accumulators in RAM and copies them to the PIC's
EEPROM every `PERSIST_INTERVAL_MS`. When the ignition goes off the RAM goes
with it, so everything since the last copy is gone: uniformly 0 to that
interval, half of it on average, **every shutdown**. It is
not a fault, it is what a periodic write means, and `canfuel/src/persist.h` has
the full account including why it is invisible on the display (FuelAvg is a
ratio and both halves shrink together, so the error lands at about 0.17 %).

Writing more often shrinks it but never removes it, and each write costs 48 ms
of blocked CPU. The only thing that removes it is knowing the shutdown is
coming and writing once, at that moment. That needs two things this board does
not have:

1. **Warning** — some signal that the supply is going away, *before* it has.
2. **Hold-up** — enough energy left to finish a twelve-byte record afterwards.

### Why the current board cannot do it

- **5 V comes straight from the display's connector C6/C12.** There is no
  regulator, no series element and no local energy store beyond C6 (10 µF) and
  the 100 nF decoupling. When the display's rail goes, ours goes with it.
- **Nothing senses the upstream side.** The firmware does measure its own VDD
  through the band gap (`hal_sys_vdd_c()`), but that is the *same* rail: by the
  time it reads low there is nothing left to write with. The measurement has to
  be of a supply the board is no longer drawing from.

### What it would take

Three parts, none of them exotic:

| | What | Why |
| --- | --- | --- |
| **D3** | Schottky in series with the 5 V feed | separates "the display's 5 V" from "our 5 V", so the bulk capacitor holds only us up and does not try to power the display |
| **C9** | bulk electrolytic on the board side of D3 | the energy that finishes the record |
| **sense** | divider or direct link from the *display* side of D3 to a spare PIC input | the warning |

The firmware side is small: poll the sense pin in the main loop — it runs 7,400
to 20,000 times a second, so no interrupt is needed and none should be added —
and on a low, call `persist_save_now()` immediately and then spin. `RB0/INT0`
exists (DS39977C §10, external interrupts on RB0/INT0, RB1/INT1) if a future
design wants an edge instead, but polling matches how the rest of that firmware
is built.

### The arithmetic

`C = I · t / ΔV`.

**Current, with the LEDs dark as they are in the car** (the `DBG_EN` jumper is
not fitted):

| | typ | max | source |
| --- | --- | --- | --- |
| PIC18F25K80, 16 MHz, VDD = 5 V, PRI_RUN | 2.2 mA | 6 mA | DS39977C Table 31-5, Supply Current IDD. The 16 MHz row's test condition is a 4 MHz EC oscillator with PLL rather than our HS1 crystal — it is the closest figure the datasheet gives, and it is quoted as such. |
| MCP2562, recessive | 5 mA | 10 mA | DS20005167C, DC Characteristics, VDD pin: `IDD -- 5 10 mA Recessive; VTXD = VDD`. The dominant figure of 45/70 mA does not apply — nothing is transmitted during a shutdown write. |
| **total** | **7.2 mA** | **16 mA** | |

**Time**: twelve bytes at 4 ms each is 48 ms (DS39977C Table 31-1, D122).
⚠ **D122 is a typical with no maximum at all**, and §8.4 says the write time
"will vary with voltage and temperature, as well as from chip-to-chip". A
hold-up design cannot be sized on a typical, so double it: **96 ms**.

**Voltage**: the brown-out trip is the floor, not the EEPROM's. `BORV = 0` in
`canfuel/src/pic_config.h` sets 3.0 V, chosen because the A/D's twelve-bit
resolution is only specified for VREF ≥ 3.0 V (DS39977C Table 31-25, A01/A50).
D121 allows EEPROM writes down to 1.8 V, so the CPU resets long before the
memory would object. With a Schottky drop of about 0.3 V the board starts at
4.7 V, giving **ΔV = 1.7 V**.

| Assumption | C required | Fit |
| --- | --- | --- |
| 16 mA max, 48 ms | 452 µF | 470 µF |
| 16 mA max, 96 ms (D122 doubled) | 904 µF | **1000 µF** |
| transceiver in standby first, 6 mA, 96 ms | 339 µF | 470 µF |

The third row is the interesting one and it needs a fourth change: **STBY would
have to come off ground and onto a pin.** On this board it is hard-wired low
(`CLAUDE.md`, Transceiver), which is right for a board that always talks. A
revision that can shut the transceiver up at the moment of the warning needs
less than half the capacitance — and 5 µA of standby current (DS20005167C,
IDDS) is nothing at all.

### Three things that would have to be checked, and one to do first

- **Measure the display's rail first, before choosing any capacitor.** How fast
  the MFD15's 5 V collapses at ignition-off is unknown and nobody has looked. If
  it decays over a hundred milliseconds under our load, most of the hold-up
  already exists and C9 could be small or unnecessary. If it snaps off in a
  millisecond, the table above stands. **This is a measurement, not a design
  decision, and it is cheap** — a scope on C6 while somebody turns the key.
- **The MCP2562 is out of specification below 4.5 V** (DS20005167C, VDD Voltage
  Range 4.5–5.5 V). During the hold-up the rail crosses that on its way to 3.0,
  so the transceiver's behaviour is undefined for the last part of the write.
  It does not matter if nothing is being transmitted, and it is another argument
  for putting it in standby rather than leaving it to guess.
- **Inrush against the fuse and the display.** C9 would be fifty to a hundred
  times C6. The feed is a SIBA 179120.0.2, 200 mA time-lag (0.7 A²s per its
  datasheet), and the display's own limit is 0.5 A — the peak charging current
  into 1000 µF is set by nothing but ESR and wiring resistance. A series
  resistor, an NTC, or accepting a slower start would all work; what would not
  work is fitting the capacitor and hoping.

### What it does not buy

Nothing else. The trip accumulators are the only state that has to survive a
power cycle, the display never shows them as absolutes, and FuelAvg is already
within a sixth of one digit. **This is a completeness fix, not a fault fix**,
and that is why it sits in this file rather than in a plan.

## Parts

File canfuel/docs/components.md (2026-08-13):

# What each passive does, and the physics that sizes it

`implementation-plan.md` records **what was chosen** for every reference
designator and which datasheet section forced it. This file answers the
question that sits underneath: **why does the physics need a part there at
all**, and why is it that value rather than one an order of magnitude away.

Nothing here overrides the plan. Where the two touch, the plan is the
specification and this is the reasoning; §3.2, §3.5, §4.3a, §4.4 and §9.2 are
the sections it leans on.

**The eight capacitors on this board do six unrelated jobs.** They are not one
family in different sizes. Two of them are not on the supply rail at all, and
one of them is not a bypass capacitor in any sense — it is a regulator's
compensation network. Confusing them is how a board gets a 100 nF part where a
10 µF one was required, which compiles, assembles and fails.

| Ref | Value | Job | Timescale it works on |
|---|---|---|---|
| C3, C4, C5 | 100 nF X7R | supply decoupling | tens of nanoseconds |
| C6 | 10 µF electrolytic | bulk / tank | microseconds to milliseconds |
| C7 | 10 µF X7R | core regulator compensation | the regulator's loop, not a rail |
| C1, C2 | 33 pF C0G | crystal load | 62.5 ns per cycle, continuously |
| C8 | 100 nF X7R | MCLR reset filter | ~1 ms |

---

## 1. The load this board presents, and how fast it changes

Every number below is driven by one fact: **the transceiver's supply current is
not constant, and the step is large compared with everything else on the
board.**

| | typ | max | Source |
|---|---|---|---|
| U1, PIC18F25K80 at FOSC = 16 MHz, VDD = 5 V, regulator enabled | 2.2 mA | 6 mA | DS39977C §31.2, *Supply Current (IDD)*, FOSC = 16 MHz row |
| U2, MCP2562, bus **recessive** | 5 mA | 10 mA | DS20005167C §2.2, *Supply Current*, `VTXD = VDD` |
| U2, MCP2562, bus **dominant** | **45 mA** | **70 mA** | DS20005167C §2.2, `VTXD = 0V` |
| D1 + D2, only with JP1 fitted | 6.4 mA | — | plan, *LED colour is free*: 3.2 mA each at Vf ≈ 1.8 V |
| R1 + R6 across the rail | 0.48 mA | — | 5 V / 10.47 kΩ |

Three totals follow, and they are three different questions:

- **Continuous, in the car** (JP1 off, bus idle between frames): about **8 mA**.
- **Continuous, worst case allowed by the datasheets**: about **16.5 mA**.
- **Instantaneous, while driving a dominant bit**: about **77 mA**.

The last one is the interesting one, because it is not a load — it is a **step**.
Going recessive → dominant, the board's draw rises by **40 mA typical, 60 mA
maximum**, and it does so inside the delay DS20005167C §2.3 parameter 3 bounds
at **70 ns** (`tTXD-BUSON`, TXD low to bus dominant). At 500 kbps that step can
repeat every 2 µs, indefinitely, for as long as the engine runs.

⚠ **Parameter 3 is a propagation delay, not a slew rate.** The datasheet
specifies no rise time for the supply current, so 70 ns is used here as the
window within which the step must have completed — an upper bound on the
timescale, not a measurement of it. A faster real edge only makes the case for
local capacitance stronger, never weaker.

---

## 2. C3, C4, C5 — decoupling, which means nanoseconds

**The physics.** Two relations do all the work in this file:

```
Q = C · V          charge stored in a capacitor
i = C · dV/dt      current is capacitance times rate of change of voltage
```

Read the second one backwards and it becomes the design tool: **a capacitor
asked to supply current `i` for a time `Δt` sags by `ΔV = i·Δt / C`.** That is
the only equation needed for C3–C6.

The counterpart on the supply side is the wire:

```
V = L · di/dt      voltage across an inductance is its rate of change of current
```

A wire is an inductor. It does not object to carrying current; it objects to
**changing** it, and the faster the change the harder it pushes back. That is
what makes a 1.4 m harness useless at nanosecond timescales, however thick the
copper is and however low its DC resistance.

**Applied here.** The 5 V feed reaches the board through roughly 1.4 m of loom
from the display. Taking **1 µH/m** as the inductance of ordinary loom wire —
⚠ **an order-of-magnitude estimate, not a datasheet figure; no document held in
this repository specifies it** — that is about 1.4 µH between the board and its
supply. Asking that inductance to deliver the transceiver's 40 mA step within
70 ns:

```
V = 1.4 µH × 0.04 A / 70 ns ≈ 0.8 V
```

**Most of a volt of collapse, on every dominant bit**, half a million times a
second, on a rail whose total headroom to the transceiver's own minimum is
0.5 V (§3 below). The estimate could be wrong by a factor of three in either
direction and the conclusion would not move: the harness cannot serve this
step, and the fix is not a better harness.

With 100 nF sitting at the pin, the same charge comes out of the capacitor
instead:

```
ΔV = i·Δt / C = 0.04 A × 70 ns / 100 nF ≈ 28 mV        (42 mV at the 60 mA max step)
```

Twenty-eight millivolts against eight hundred. **That is the whole of what a
decoupling capacitor is for** — not storing energy, of which 100 nF has almost
none, but being physically close enough that no inductance stands between the
charge and the pin that needs it.

**Which is why DS39977C §2.2.1 is a placement rule as much as a value rule**:
100 nF, ceramic, low-ESR, and *"the trace length from the pin to the capacitor
is no greater than 0.25 inch (6 mm)"*. Exceed the 6 mm and the capacitor
acquires its own share of the inductance the exercise above was trying to
avoid, and stops being able to do the one thing it was fitted for.
`tools/check-placement.py` measures all three distances for exactly this
reason.

**Why three of them and not one.** §2.2.1 asks for decoupling *on every pair of
supply pins*. The board has three such pins — U1 VDD (pin 20), U2 VDD (pin 3),
U2 VIO (pin 5) — and the copper between any two of them is itself inductance.
One shared capacitor would be within 6 mm of at most one pin.

**Why X7R and not C0G here.** Only the capacitance matters, no frequency is
being set, and X7R gets far more capacitance into a 2.54 mm part than C0G. The
opposite trade-off applies to C1/C2 in §5.

---

## 3. C6 — bulk, which means microseconds

100 nF covers the edge. It cannot cover the **whole dominant bit**, and the
arithmetic says so immediately.

CAN inserts a stuff bit after five identical bits, so in normal traffic the
longest unbroken dominant run is five bit times = **10 µs** at 500 kbps:

```
Q = 40 mA × 10 µs = 400 nC
on 100 nF alone:   ΔV = 400 nC / 100 nF = 4 V      ← impossible
on 10.3 µF:        ΔV = 400 nC / 10.3 µF ≈ 39 mV   ← this is C6
```

That is the division of labour, and it is why one capacitor cannot replace two:
**C4 supplies the edge, C6 supplies the bit.** The short PCB track between them
is what separates their roles — its inductance is negligible over 10 µs and
decisive over 70 ns.

The worst case is not a stuffed frame but an error frame: an error flag is six
dominant bits and superimposed flags can reach twelve, with no stuffing. At
12 bits = 24 µs the same sum gives 960 nC and **93 mV** on 10.3 µF, still
comfortable.

**10.3 µF, not 20 µF.** The capacitance available to the transceiver is C6 plus
the three 100 nF parts. **C7 is not part of it** — it sits on VDDCORE, behind
the on-chip regulator, and a series pass regulator does not deliver charge
backwards into its own input. See §4.

**DS39977C §2.2.2 arrives at the same part from a different direction**: a tank
capacitor is asked for on boards whose power traces run longer than six inches,
sized *"based on the trace resistance ... and the maximum current drawn by the
device"* so as to meet an acceptable sag, with a range of 4.7 µF to 47 µF. A
1.4 m harness is well past six inches, so this is that case, and 10 µF sits in
the lower half of the range because the sums above show the lower half is
enough.

**C6 must stay downstream of the harness fuse, and that is load-bearing.** The
SIBA 179120.0.2 drops 500 mV at its rated 200 mA (plan §9.2), i.e. **2.5 Ω of
hot element**, against 0.51 V of headroom between the 5.01 V measured at the
display connector and the MCP2562's 4.5 V minimum. If the transceiver's 45–70 mA
dominant current had to cross that element, it would cost 110–175 mV of the
0.51 V on every dominant bit. Because C6 is on the board side of it, the fuse
only ever sees the **average**, which is under 30 mA — 75 mV. A bulk capacitor
on the display side of the fuse would not have worked.

---

## 4. C7 — a regulator's compensation capacitor, and nothing else

**Pin 6 is not a supply pin.** The 28-pin PIC18F25K80 has no RA4 and no ENVREG:
pin 6 is VDDCORE/VCAP, the **output** of an on-chip regulator that makes the
core rail from VDD. DS39977C §2.4 requires *"a low-ESR (< 5 Ω) capacitor ... to
stabilize the voltage regulator output voltage"*, of **10 µF**, and states
outright that the pin *"must not be connected to VDD"*.

**Stability, not storage.** A linear regulator is a feedback loop: it compares
its output against an internal reference and drives a pass device to correct
the difference. Every feedback loop has a phase margin, and the output
capacitor is part of the network that sets it. Too little capacitance, or too
much series resistance in it, and the loop's phase margin goes negative — the
regulator oscillates instead of regulating, and the core rail the CPU runs on
develops ripple that no amount of decoupling elsewhere can remove. This is why
§2.4 specifies both a value **and** an ESR ceiling, and why Figure 2-3 plots
ESR against frequency: the capacitor here is a circuit element inside a control
loop, not a reservoir.

Three consequences, all visible on the board:

- **Ceramic, not electrolytic.** An aluminium electrolytic's ESR is typically
  ohms, which is where §2.4's 5 Ω ceiling lives. §2.4 admits ceramic or tantalum
  and nothing else, and Table 2-1 names four ceramic parts outright — one of
  which, `GRM32DR71C106KA01L`, is what is fitted. C6 being the same nominal
  10 µF makes it look like a substitute. It is not.
- **The only SMD part on the board, on the bottom, under pin 6.** §2.4 puts the
  same 6 mm limit on this trace as §2.2.1 does on decoupling, for the same
  reason: inductance between the capacitor and the pin is inductance inside the
  control loop. As built it is 2.25 mm.
- **It cannot help the 5 V rail.** Charge in C7 is on the regulator's output
  side. It will hold the *core* up briefly while VDD sags, which is real but
  invisible, because the brown-out detector on VDD trips first (§5). It
  contributes nothing to the transceiver's dominant-bit current and nothing to
  ride-through of the 5 V rail.

---

## 5. How long the board survives a supply interruption

This is the question C6 gets asked most often, and its honest answer is
**shorter than intuition suggests, and it is not what C6 is for.**

The equation is the same one as everywhere else, rearranged for time:

```
Δt = C · ΔV / i
```

**The floor is not obvious, because there are two of them, and the higher one
belongs to the transceiver:**

- **4.5 V — the MCP2562 leaves its specified range.** DS20005167C §2.2 gives
  VDD as 4.5 V to 5.5 V. Below that the part is not guaranteed to do anything
  in particular; its own POR comparator does not trip until VPORL, 3.4–4.0 V,
  so there is an unspecified band in between.
- **3.18 V — the PIC resets.** `BORV<1:0> = 00` selects a brown-out trip of
  **2.82 / 3.0 / 3.18 V** min/typ/max (DS39977C parameter D005). The worst case
  is the one to design against, so 3.18 V.

So the transceiver falls out of specification **well before** the microcontroller
notices anything is wrong. With C = 10.3 µF and starting from 5.0 V:

| Floor | ΔV | at 8 mA | at 16.5 mA |
|---|---|---|---|
| 4.5 V — everything still in specification | 0.5 V | **640 µs** | **310 µs** |
| 3.18 V — the PIC is still executing | 1.82 V | 2.3 ms | 1.1 ms |

**Hundreds of microseconds, not milliseconds.** Turning that into 3 ms of
ride-through at 20 mA down to 4.5 V would take `C = i·Δt/ΔV` = **120 µF**, a
part with no place on this board and no purpose on it either.

**Which is the point: C6 is not a hold-up capacitor and was never sized as
one.** §2.2.2 sizes a tank capacitor for *sag under load steps across a long
supply run*, which §2 and §3 above are the working for. Ride-through is a
by-product. It also could not be otherwise: the 5 V comes from the display,
which has its own supply and its own bulk capacitance, so an interruption long
enough to exhaust 10 µF on this board has already taken down the device these
numbers are being computed for.

**Deliberate loss of the supply is a different problem and has a different
answer.** Ignition-off is not a transient to be ridden out; it is an event the
firmware would want to be told about, so it can write its accumulators before
the rail goes. That is a hold-up supply plus a sense line, three parts and a
sense pin, and it is written up in `revision-b.md`. It is not this capacitor
made bigger.

---

## 6. C1, C2 — not a supply job at all

These belong to the oscillator. A Pierce oscillator presents the crystal with a
capacitive load, and **a quartz crystal only runs at its marked frequency when
it sees the load capacitance it was cut for.** Load it differently and it still
oscillates, at a slightly different frequency — which matters here because CAN
bit timing is derived from it, and every node on the bus has to agree.

The two capacitors appear in series as seen by the crystal, plus whatever the
pins and tracks contribute:

```
CL = C1·C2/(C1+C2) + Cstray
```

With C1 = C2 = C this inverts to `C = 2·(CL − Cstray)`. The crystal specifies
**CL = 20 pF**, and with about 5 pF of stray:

```
C = 2 · (20 − 5) = 30 pF   →  33 pF, the nearest E12 value
```

**Not the 22 pF that gets fitted from habit.** DS39977C Table 3-3 lists 27 pF at
4 MHz, 22 pF at 8 MHz and 15 pF at 20 MHz with no 16 MHz row at all, and its
note 3 defers to the crystal manufacturer — so the table cannot settle it and
the crystal does. Plan §3.2 has the full derivation, including why an earlier
belief that CL was 32 pF was wrong and what it would have implied.

**C0G/NP0 dielectric here, where C3–C5 are X7R.** X7R's capacitance moves by
tens of percent with temperature and DC bias. On a decoupling capacitor that is
tolerable; on the load capacitance that sets an oscillator's frequency, in a
part that lives behind a dashboard vent, it is not.

---

## 7. C8, R1, R6 — filtering a reset, not a supply

The MCLR network is DS39977C Figure 2-2 in full: R1 10 kΩ pull-up, R6 470 Ω in
series into pin 1, C8 100 nF to ground behind jumper JP2.

**R1 and C8 are a low-pass filter with a time constant of about 1 ms**
(`τ = R·C` = 10 kΩ × 100 nF). §2.3 asks for the capacitor to increase *"the
application's resistance to spurious Resets from voltage sags"* — a transient
shorter than τ cannot pull the pin far enough to be seen as a reset, while a
genuine sag lasting longer than that still resets the part, which is the wanted
behaviour.

**R6 is not part of the filter.** Figure 2-2 note 2: *"R2 ≤ 470 Ω will limit any
current flowing into MCLR from the external capacitor C, in the event of MCLR
pin breakdown, due to Electrostatic Discharge (ESD) or Electrical Overstress
(EOS)."* C8 stores charge; if the pin ever breaks down, that charge would
otherwise dump into the die through a short. R6 has to sit between the RC node
and the pin — anywhere else it cannot do this — which is exactly where the
schematic puts it.

**And the same paragraph is why JP2 exists.** A programmer drives MCLR and needs
fast edges on it; 100 nF with 1 ms of time constant is precisely what stops
that working, so §2.3 asks for the capacitor and hands it a jumper in the same
breath. JP2 comes off before programming and goes back afterwards.

---

## 8. What in this file is not from a datasheet

Per the sourcing rule in `CLAUDE.md`, everything above is either cited or is
listed here:

- **1 µH/m of harness inductance** (§2) — an order-of-magnitude estimate. No
  document held here specifies it, and the harness wire is a commodity part with
  no datasheet. It is used only to show that the harness cannot serve a 70 ns
  current step; the conclusion survives an error of several times in either
  direction, and the design does not depend on the value.
- **~5 pF of stray capacitance** at the oscillator pins (§6) — the same estimate
  the plan §3.2 uses, carried here unchanged rather than re-derived.
- **Treating parameter 3's 70 ns as the current step's timescale** (§1) — the
  datasheet bounds a propagation delay, not a supply-current slew rate. Used as
  an upper bound, which is the conservative direction.
- **The three current totals** (§1) — arithmetic on the cited rows, not figures
  read anywhere.

Everything else names its document and section.

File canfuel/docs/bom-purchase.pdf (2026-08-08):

# Nákupní seznam — převodník canfuel (revize 2)

Stav k 2. 8. 2026.

## Jak to bude zapojené

Na desce jsou dva stejné headery s kolíky (43045-0400), zapojené paralelně na tytéž čtyři nety: CAN-H, CAN-L, 5 V, SGND. Oba kabely končí pouzdrem s dutinkami (43025-0400) — tedy vypadají stejně jako to, co dnes zasunuješ do zadní strany MFD15.

Důsledky, které z toho plynou:

Záměna konektorů je úplně neškodná. Nety jsou na obou headerech totožné, takže je jedno, který kabel kam zastrčíš.

5 V fyzicky přivádí jen jeden kabel (ten od plugu C). Kabel od auta má osazené jen dvě pozice, ostatní zůstanou prázdné. Deska napájení dostane z toho, který ho nese, ať je zastrčený kdekoliv.

Deska sama je propojkou CAN. CAN-H i CAN-L vedou mezi headery měděnou cestou, takže sběrnice k displeji jde skrz desku i tehdy, když je PIC vytažený z patice.

Bypass test před výrobou desky uděláš dočasným spojením holých vodičů (žlutá k žluté, bílá k bílé), tedy ještě než dutinky zasuneš do pouzder. Žádná spojka, žádný krimp navíc.

## 1. Nářadí

Co | Označení | Ks | Kde
Krimpovací kleště | Pro’sKit CP-3006FD36 | 1 | GME kód 1504590
Vytahovák pinů, univerzální sada | „extraction tool set” pro automotive konektory | 1 | GME / Alza — sada s více tvary trnů, ne jeden kus

Sadu chtěj kvůli tomu, že potřebuješ jiný tvar na Micro-Fit (obdélníková dutina) a jiný na ten ACI konektor v autě (kulatá).

## 2. Konektory Micro-Fit 3.0

Co | Molex | Ks | Kde
Header do DPS, 4pin, pravoúhlý | 43045-0400 | 4 | GME kód 1502884
Pouzdro s dutinkami, 4pin | 43025-0400 | 4 | GME, jinak Farnell kód 672890
Dutinka, 20–24 AWG | 43030-0007 | 30 | GME kód 840-034, ~3 Kč/ks

Kolíky 43031 ani pouzdra 43020 nepotřebuješ — spojka odpadla.

Rozpis dutinek, ať víš, proč třicet:

Kam | Ks
Svazek od auta → převodník (jen CAN-H/L) | 2
Svazek od plugu C → převodník (CAN-H/L + 5 V + SGND) | 4
Nové delší napájecí vodiče do plugu B | 2
Plug C (12pin) | 0 — použiješ nakrimpované od CANchecked
Cvičné krimpy a rezerva | zbytek

Ostrá potřeba je tedy 8 kusů. Zbytek je na to, aby ses do prvních krimpů mohl trefovat bez počítání, a na příště.

## 3. Vodiče

Co | Ks
Licna 0,5 mm², červená | 1 m
Licna 0,5 mm², černá | 1 m
Licna 0,5 mm², žlutá | 1 m
Licna 0,5 mm², bílá | 1 m

Musí to být licna, ne pevný drát — pevné jádro v autě praská vibracemi, typicky přímo za krimpem.

## 4. Aktivní součástky

Co | Označení | Ks | Poznámka
CAN transceiver | MCP2562-E/P | 3 | přípona -E/P = PDIP-8; -E/SN je SOIC, ten nechceš
Krystal 16 MHz | HC-49/S nebo HC-49/U | 3

PIC18F25K80 máš doma.

## 5. Pasivní součástky a drobnosti

Přesné hodnoty vypadnou až ze schématu; tohle je zásoba, se kterou postavíš breadboard i finální desku bez ohledu na to, jak návrh dopadne.

Co | Ks
Keramický kondenzátor 22 pF | 10
Keramický kondenzátor 100 nF | 20
Elektrolyt nebo tantal 10 µF / 25 V | 5
Rezistor 10 kΩ | 10
Rezistor 4,7 kΩ | 10
Rezistor 1 kΩ | 10
LED 3 mm, dvě barvy | po 5
DIP patice 28 pin úzká | 3
DIP patice 8 pin | 3
Kolíková lišta 2,54 mm, lámací | 2

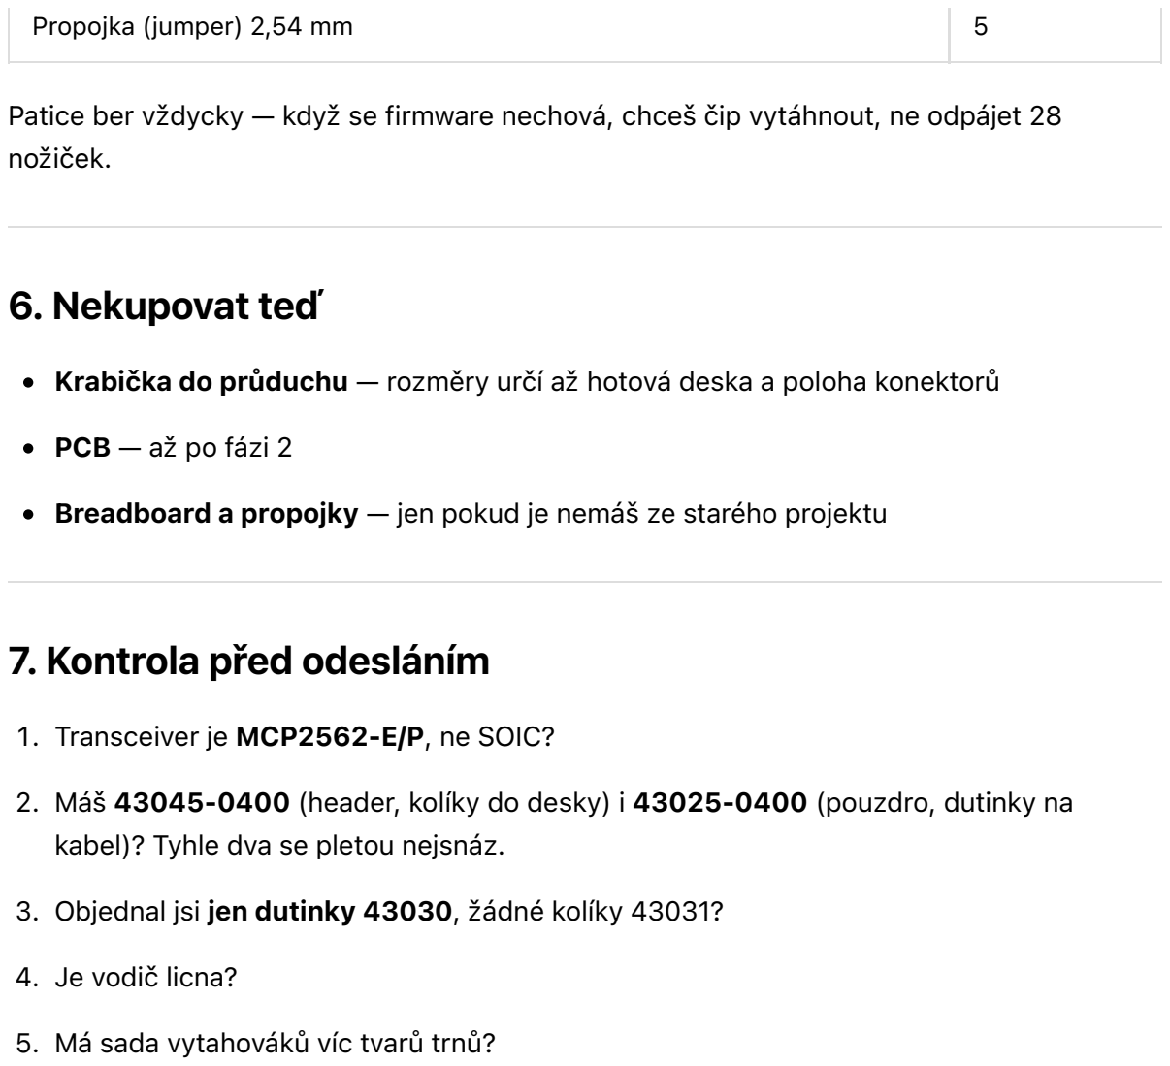
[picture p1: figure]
Propojka (jumper) 2,54 mm; nožiček.; 6. Nekupovat teď; PCB — až po fázi 2; 7. Kontrola před odesláním; 1. Transceiver je MCP2562-E/P, ne SOIC?; kabel)? Tyhle dva se pletou nejsnáz.; 4. Je vodič licna?; 5. Má sada vytahováků víc tvarů trnů?

Patice ber vždycky — když se firmware nechová, chceš čip vytáhnout, ne odpájet 28

Krabička do průduchu — rozměry určí až hotová deska a poloha konektorů

Breadboard a propojky — jen pokud je nemáš ze starého projektu

2. Máš 43045-0400 (header, kolíky do desky) i 43025-0400 (pouzdro, dutinky na
3. Objednal jsi jen dutinky 43030, žádné kolíky 43031?

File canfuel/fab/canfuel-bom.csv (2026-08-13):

Refs | Value | Footprint | Qty | DNP
C1,C2 | 33p | Capacitor_THT:C_Disc_D5.0mm_W2.5mm_P5.00mm | 2
C3-C5 | 100n | Capacitor_THT:C_Disc_D5.0mm_W2.5mm_P5.00mm | 3
C6 | 10u | Capacitor_THT:CP_Radial_D5.0mm_P2.00mm | 1
C7 | 10u | Capacitor_SMD:C_1210_3225Metric_Pad1.33x2.70mm_HandSolder | 1
C8 | 100n | Capacitor_THT:C_Disc_D5.0mm_W2.5mm_P2.50mm | 1
D1 | red | LED_THT:LED_D3.0mm | 1
D2 | yellow | LED_THT:LED_D3.0mm | 1
J1,J2 | Micro-Fit 43045-0400 | Connector_Molex:Molex_Micro-Fit_3.0_43045-0400_2x02_P3.00mm_Horizontal | 2
J3 | ICSP | Connector_PinHeader_2.54mm:PinHeader_1x05_P2.54mm_Vertical | 1
JP1 | DBG | Connector_PinHeader_2.54mm:PinHeader_1x02_P2.54mm_Vertical | 1
JP2 | MCLR | Connector_PinHeader_2.54mm:PinHeader_1x02_P2.54mm_Vertical | 1
R1,R2 | 10k | Resistor_THT:R_Axial_DIN0207_L6.3mm_D2.5mm_P2.54mm_Vertical | 2
R3,R4 | 1k | Resistor_THT:R_Axial_DIN0207_L6.3mm_D2.5mm_P2.54mm_Vertical | 2
R6 | 470R | Resistor_THT:R_Axial_DIN0207_L6.3mm_D2.5mm_P2.54mm_Vertical | 1
U1 | PIC18F25K80 | Package_DIP:DIP-28_W7.62mm_Socket | 1
U2 | MCP2562-E/P | Package_DIP:DIP-8_W7.62mm_Socket | 1
Y1 | 16MHz | Crystal:Crystal_HC49-U_Vertical | 1

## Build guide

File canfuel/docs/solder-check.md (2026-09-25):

<!-- Generated by kicad/tools/render-solder-check.py. Do not edit. -->

# After each joint: what must read zero, and what must not

`canfuel/docs/firmware/install.md` step 5 has you measure every part **before** it
goes in, which catches a misread colour code and nothing else. This is the
other half, and it is per **joint** rather than per part.

A soldered joint fails in two directions and neither one is visible:

- **open** — the iron never wetted the pad, or the lead moved as it cooled
- **bridged** — solder reached the nearest copper, which is hardly ever the
  next pad along

So every pad gets two readings. **Continuity** proves the joint exists;
**isolation** proves nothing else got caught. Look the second one up rather
than guessing it — SGND is poured on both layers, so for most pads the
nearest copper is ground, a fraction of a millimetre away, on every side.

## How to hold the meter

- **Continuity (beeper) for the "zero" column.** A joint either rings or
  it does not.
- **Resistance, not the beeper, for anything with a capacitor across it.**
  A 10 µF part charges through the meter, so the beeper chirps once and
  goes quiet. That chirp is the capacitor, not a bridge. Watch the number
  climb instead: it must settle in megohms or `OL`. A steady near-zero that
  never moves is a bridge.
- **Measure with nothing else fitted yet**, which is what the solder order
  in install.md gives you for free. Once the neighbours are in, every
  reading is of whatever else shares the net.
- **The distances below are copper edge to copper edge, as designed.**
  Solder mask sits between most of them, which makes a bridge less likely
  and not impossible. Anything under about 0.6 mm is worth the ten
  seconds.

## How to read it

Find the part you have just soldered. Every one of its pads gets a row.

- **`—` in the zero column** means the pad is on no net. Fourteen of U1's
  pins are like that: the pin goes nowhere and there is nothing it should
  ring to. Its **open** column still matters — the firmware drives every
  unused pin low, so a bridge from one of them to +5 V is a short through
  the port driver.
- **U1 and U2 are the socket holes**, so their rows are checked once the
  socket is soldered and before either chip goes in. That is also the only
  time the holes are reachable.
- **A named probe point is a hole you can find by eye** — `J3 pin 1` is the
  square pad of the ICSP header, `U1 pin 1` the end the silk notch marks.
  Where several are listed, any of them will do.

## C1 — 33p

| Pad | Net | Must read **zero** to | Must stay **open** to |
|---|---|---|---|
| 1 | OSC1 | U1 pin 9, Y1 pad 1 | **SGND** 0.30 mm (any ground — J3 pin 3) |
| 2 | SGND | any ground — J3 pin 3 | nothing within 1.0 mm |

## C2 — 33p

| Pad | Net | Must read **zero** to | Must stay **open** to |
|---|---|---|---|
| 1 | OSC2 | U1 pin 10, Y1 pad 2 | **SGND** 0.30 mm (any ground — J3 pin 3); **DBG_EN** 0.57 mm (JP1 pin 2, U1 pin 2, R2 pad 1) |
| 2 | SGND | any ground — J3 pin 3 | **DBG_EN** 0.57 mm (JP1 pin 2, U1 pin 2, R2 pad 1) |

## C3 — 100n

| Pad | Net | Must read **zero** to | Must stay **open** to |
|---|---|---|---|
| 1 | +5V | any +5 V pin — J3 pin 2 | **SGND** 0.30 mm (any ground — J3 pin 3); **PGC** 0.80 mm (J3 pin 5, U1 pin 27) |
| 2 | SGND | any ground — J3 pin 3 | **+5V** 0.40 mm (any +5 V pin — J3 pin 2); **PGC** 0.47 mm (J3 pin 5, U1 pin 27) |

## C4 — 100n

| Pad | Net | Must read **zero** to | Must stay **open** to |
|---|---|---|---|
| 1 | +5V | any +5 V pin — J3 pin 2 | **SGND** 0.30 mm (any ground — J3 pin 3); **PGD** 0.87 mm (J3 pin 4, U1 pin 28) |
| 2 | SGND | any ground — J3 pin 3 | **PGD** 0.87 mm (J3 pin 4, U1 pin 28) |

## C5 — 100n

| Pad | Net | Must read **zero** to | Must stay **open** to |
|---|---|---|---|
| 1 | +5V | any +5 V pin — J3 pin 2 | **SGND** 0.30 mm (any ground — J3 pin 3); **~MCLR** 0.80 mm (J3 pin 1, U1 pin 1, R6 pad 2) |
| 2 | SGND | any ground — J3 pin 3 | **CANL** 0.40 mm (J1 pin 4, J2 pin 4, U2 pin 6); **CANH** 0.40 mm (J1 pin 3, J2 pin 3, U2 pin 7) |

## C6 — 10u

| Pad | Net | Must read **zero** to | Must stay **open** to |
|---|---|---|---|
| 1 | +5V | any +5 V pin — J3 pin 2 | **SGND** 0.30 mm (any ground — J3 pin 3) |
| 2 | SGND | any ground — J3 pin 3 | **+5V** 0.40 mm (any +5 V pin — J3 pin 2) |

## C7 — 10u *(bottom side)*

| Pad | Net | Must read **zero** to | Must stay **open** to |
|---|---|---|---|
| 1 | VCAP | U1 pin 6 | **SGND** 0.30 mm (any ground — J3 pin 3); **DBG_EN** 0.37 mm (JP1 pin 2, U1 pin 2, R2 pad 1) |
| 2 | SGND | any ground — J3 pin 3 | **PGC** 0.38 mm (J3 pin 5, U1 pin 27); **CAN_TX** 0.79 mm (U1 pin 23, U2 pin 1) |

## C8 — 100n

| Pad | Net | Must read **zero** to | Must stay **open** to |
|---|---|---|---|
| 1 | MCLR_C | JP2 pin 2 | **SGND** 0.30 mm (any ground — J3 pin 3); **+5V** 0.40 mm (any +5 V pin — J3 pin 2); **MCLR_RC** 0.58 mm (JP2 pin 1, R1 pad 2, R6 pad 1) |
| 2 | SGND | any ground — J3 pin 3 | **MCLR_RC** 0.38 mm (JP2 pin 1, R1 pad 2, R6 pad 1); **MCLR_C** 0.90 mm (JP2 pin 2, C8 pad 1) |

## D1 — red

| Pad | Net | Must read **zero** to | Must stay **open** to |
|---|---|---|---|
| 1 | SGND | any ground — J3 pin 3 | **LED_PWR_A** 0.74 mm (D1 pad 2, R3 pad 2) |
| 2 | LED_PWR_A | R3 pad 2 | **SGND** 0.30 mm (any ground — J3 pin 3); **LED_PWR** 0.33 mm (U1 pin 11, R3 pad 1) |

## D2 — yellow

| Pad | Net | Must read **zero** to | Must stay **open** to |
|---|---|---|---|
| 1 | SGND | any ground — J3 pin 3 | **LED_CAN_A** 0.74 mm (D2 pad 2, R4 pad 2) |
| 2 | LED_CAN_A | R4 pad 2 | **SGND** 0.30 mm (any ground — J3 pin 3) |

## J1 — Micro-Fit 43045-0400

| Pad | Net | Must read **zero** to | Must stay **open** to |
|---|---|---|---|
| 1 | +5V | any +5 V pin — J3 pin 2 | **SGND** 0.30 mm (any ground — J3 pin 3); **~MCLR** 0.92 mm (J3 pin 1, U1 pin 1, R6 pad 2) |
| 2 | SGND | any ground — J3 pin 3 | **~MCLR** 0.93 mm (J3 pin 1, U1 pin 1, R6 pad 2) |
| 3 | CANH | J2 pin 3, U2 pin 7 | **SGND** 0.30 mm (any ground — J3 pin 3); **~MCLR** 0.33 mm (J3 pin 1, U1 pin 1, R6 pad 2); **+5V** 0.35 mm (any +5 V pin — J3 pin 2) |
| 4 | CANL | J2 pin 4, U2 pin 6 | **SGND** 0.30 mm (any ground — J3 pin 3); **~MCLR** 0.33 mm (J3 pin 1, U1 pin 1, R6 pad 2); **+5V** 0.35 mm (any +5 V pin — J3 pin 2) |

## J2 — Micro-Fit 43045-0400

| Pad | Net | Must read **zero** to | Must stay **open** to |
|---|---|---|---|
| 1 | +5V | any +5 V pin — J3 pin 2 | **SGND** 0.30 mm (any ground — J3 pin 3); **~MCLR** 0.33 mm (J3 pin 1, U1 pin 1, R6 pad 2) |
| 2 | SGND | any ground — J3 pin 3 | **~MCLR** 0.33 mm (J3 pin 1, U1 pin 1, R6 pad 2) |
| 3 | CANH | J1 pin 3, U2 pin 7 | **SGND** 0.30 mm (any ground — J3 pin 3); **CANL** 0.45 mm (J1 pin 4, J2 pin 4, U2 pin 6) |
| 4 | CANL | J1 pin 4, U2 pin 6 | **SGND** 0.30 mm (any ground — J3 pin 3); **CANH** 0.45 mm (J1 pin 3, J2 pin 3, U2 pin 7) |

## J3 — ICSP

| Pad | Net | Must read **zero** to | Must stay **open** to |
|---|---|---|---|
| 1 | ~MCLR | U1 pin 1, R6 pad 2 | **SGND** 0.30 mm (any ground — J3 pin 3); **+5V** 0.35 mm (any +5 V pin — J3 pin 2) |
| 2 | +5V | any +5 V pin — J3 pin 2 | **SGND** 0.30 mm (any ground — J3 pin 3); **~MCLR** 0.84 mm (J3 pin 1, U1 pin 1, R6 pad 2) |
| 3 | SGND | any ground — J3 pin 3 | **+5V** 0.45 mm (any +5 V pin — J3 pin 2); **PGD** 0.84 mm (J3 pin 4, U1 pin 28) |
| 4 | PGD | U1 pin 28 | **SGND** 0.30 mm (any ground — J3 pin 3); **PGC** 0.84 mm (J3 pin 5, U1 pin 27) |
| 5 | PGC | U1 pin 27 | **SGND** 0.30 mm (any ground — J3 pin 3); **PGD** 0.33 mm (J3 pin 4, U1 pin 28) |

## JP1 — DBG

| Pad | Net | Must read **zero** to | Must stay **open** to |
|---|---|---|---|
| 1 | +5V | any +5 V pin — J3 pin 2 | **SGND** 0.30 mm (any ground — J3 pin 3); **DBG_EN** 0.84 mm (JP1 pin 2, U1 pin 2, R2 pad 1) |
| 2 | DBG_EN | U1 pin 2, R2 pad 1 | **SGND** 0.30 mm (any ground — J3 pin 3); **+5V** 0.84 mm (any +5 V pin — J3 pin 2) |

## JP2 — MCLR

| Pad | Net | Must read **zero** to | Must stay **open** to |
|---|---|---|---|
| 1 | MCLR_RC | R1 pad 2, R6 pad 1 | **SGND** 0.30 mm (any ground — J3 pin 3); **~MCLR** 0.40 mm (J3 pin 1, U1 pin 1, R6 pad 2); **MCLR_C** 0.53 mm (JP2 pin 2, C8 pad 1) |
| 2 | MCLR_C | C8 pad 1 | **SGND** 0.30 mm (any ground — J3 pin 3); **~MCLR** 0.41 mm (J3 pin 1, U1 pin 1, R6 pad 2); **+5V** 0.77 mm (any +5 V pin — J3 pin 2) |

## R1 — 10k

| Pad | Net | Must read **zero** to | Must stay **open** to |
|---|---|---|---|
| 1 | +5V | any +5 V pin — J3 pin 2 | **SGND** 0.30 mm (any ground — J3 pin 3); **MCLR_RC** 0.94 mm (JP2 pin 1, R1 pad 2, R6 pad 1) |
| 2 | MCLR_RC | JP2 pin 1, R6 pad 1 | **SGND** 0.30 mm (any ground — J3 pin 3); **+5V** 0.40 mm (any +5 V pin — J3 pin 2) |

## R2 — 10k

| Pad | Net | Must read **zero** to | Must stay **open** to |
|---|---|---|---|
| 1 | DBG_EN | JP1 pin 2, U1 pin 2 | **SGND** 0.30 mm (any ground — J3 pin 3) |
| 2 | SGND | any ground — J3 pin 3 | **DBG_EN** 0.94 mm (JP1 pin 2, U1 pin 2, R2 pad 1) |

## R3 — 1k

| Pad | Net | Must read **zero** to | Must stay **open** to |
|---|---|---|---|
| 1 | LED_PWR | U1 pin 11 | **SGND** 0.30 mm (any ground — J3 pin 3); **LED_PWR_A** 0.94 mm (D1 pad 2, R3 pad 2) |
| 2 | LED_PWR_A | D1 pad 2 | **SGND** 0.30 mm (any ground — J3 pin 3); **LED_PWR** 0.87 mm (U1 pin 11, R3 pad 1) |

## R4 — 1k

| Pad | Net | Must read **zero** to | Must stay **open** to |
|---|---|---|---|
| 1 | LED_CAN | U1 pin 12 | **SGND** 0.30 mm (any ground — J3 pin 3); **LED_CAN_A** 0.94 mm (D2 pad 2, R4 pad 2) |
| 2 | LED_CAN_A | D2 pad 2 | **SGND** 0.30 mm (any ground — J3 pin 3); **LED_CAN** 0.38 mm (U1 pin 12, R4 pad 1) |

## R6 — 470R

| Pad | Net | Must read **zero** to | Must stay **open** to |
|---|---|---|---|
| 1 | MCLR_RC | JP2 pin 1, R1 pad 2 | **SGND** 0.30 mm (any ground — J3 pin 3); **~MCLR** 0.46 mm (J3 pin 1, U1 pin 1, R6 pad 2) |
| 2 | ~MCLR | J3 pin 1, U1 pin 1 | **SGND** 0.30 mm (any ground — J3 pin 3); **MCLR_RC** 0.89 mm (JP2 pin 1, R1 pad 2, R6 pad 1) |

## U1 — PIC18F25K80

| Pad | Net | Must read **zero** to | Must stay **open** to |
|---|---|---|---|
| 1 | ~MCLR | J3 pin 1, R6 pad 2 | **SGND** 0.30 mm (any ground — J3 pin 3); **+5V** 0.38 mm (any +5 V pin — J3 pin 2); **MCLR_C** 0.46 mm (JP2 pin 2, C8 pad 1) |
| 2 | DBG_EN | JP1 pin 2, R2 pad 1 | **SGND** 0.30 mm (any ground — J3 pin 3); **+5V** 0.40 mm (any +5 V pin — J3 pin 2); **~MCLR** 0.94 mm (J3 pin 1, U1 pin 1, R6 pad 2) |
| 3 | — | — | **SGND** 0.30 mm (any ground — J3 pin 3); **+5V** 0.54 mm (any +5 V pin — J3 pin 2); **DBG_EN** 0.81 mm (JP1 pin 2, U1 pin 2, R2 pad 1) |
| 4 | — | — | **SGND** 0.30 mm (any ground — J3 pin 3) |
| 5 | — | — | **SGND** 0.30 mm (any ground — J3 pin 3); **VCAP** 0.94 mm (U1 pin 6, C7 pad 1) |
| 6 | VCAP | C7 pad 1 | **SGND** 0.30 mm (any ground — J3 pin 3) |
| 7 | — | — | **SGND** 0.30 mm (any ground — J3 pin 3); **DBG_EN** 0.91 mm (JP1 pin 2, U1 pin 2, R2 pad 1); **VCAP** 0.94 mm (U1 pin 6, C7 pad 1) |
| 8 | SGND | any ground — J3 pin 3 | **DBG_EN** 0.48 mm (JP1 pin 2, U1 pin 2, R2 pad 1); **OSC1** 0.94 mm (U1 pin 9, C1 pad 1, Y1 pad 1) |
| 9 | OSC1 | C1 pad 1, Y1 pad 1 | **SGND** 0.30 mm (any ground — J3 pin 3); **DBG_EN** 0.48 mm (JP1 pin 2, U1 pin 2, R2 pad 1); **OSC2** 0.94 mm (U1 pin 10, C2 pad 1, Y1 pad 2) |
| 10 | OSC2 | C2 pad 1, Y1 pad 2 | **SGND** 0.30 mm (any ground — J3 pin 3); **DBG_EN** 0.48 mm (JP1 pin 2, U1 pin 2, R2 pad 1); **LED_PWR** 0.94 mm (U1 pin 11, R3 pad 1) |
| 11 | LED_PWR | R3 pad 1 | **SGND** 0.30 mm (any ground — J3 pin 3); **DBG_EN** 0.48 mm (JP1 pin 2, U1 pin 2, R2 pad 1); **OSC2** 0.90 mm (U1 pin 10, C2 pad 1, Y1 pad 2) |
| 12 | LED_CAN | R4 pad 1 | **SGND** 0.30 mm (any ground — J3 pin 3); **DBG_EN** 0.36 mm (JP1 pin 2, U1 pin 2, R2 pad 1); **LED_PWR** 0.53 mm (U1 pin 11, R3 pad 1) |
| 13 | — | — | **SGND** 0.30 mm (any ground — J3 pin 3); **DBG_EN** 0.33 mm (JP1 pin 2, U1 pin 2, R2 pad 1); **LED_CAN** 0.92 mm (U1 pin 12, R4 pad 1) |
| 14 | — | — | **SGND** 0.30 mm (any ground — J3 pin 3); **+5V** 0.40 mm (any +5 V pin — J3 pin 2) |
| 15 | — | — | **SGND** 0.30 mm (any ground — J3 pin 3); **LED_PWR** 0.70 mm (U1 pin 11, R3 pad 1) |
| 16 | — | — | **SGND** 0.30 mm (any ground — J3 pin 3); **+5V** 0.48 mm (any +5 V pin — J3 pin 2); **LED_PWR** 0.70 mm (U1 pin 11, R3 pad 1) |
| 17 | — | — | **SGND** 0.30 mm (any ground — J3 pin 3); **+5V** 0.42 mm (any +5 V pin — J3 pin 2); **LED_PWR** 0.83 mm (U1 pin 11, R3 pad 1) |
| 18 | — | — | **SGND** 0.30 mm (any ground — J3 pin 3); **+5V** 0.42 mm (any +5 V pin — J3 pin 2) |
| 19 | SGND | any ground — J3 pin 3 | **+5V** 0.42 mm (any +5 V pin — J3 pin 2) |
| 20 | +5V | any +5 V pin — J3 pin 2 | **SGND** 0.30 mm (any ground — J3 pin 3); **PGC** 0.38 mm (J3 pin 5, U1 pin 27) |
| 21 | — | — | **SGND** 0.30 mm (any ground — J3 pin 3); **PGC** 0.32 mm (J3 pin 5, U1 pin 27); **+5V** 0.59 mm (any +5 V pin — J3 pin 2) |
| 22 | — | — | **SGND** 0.30 mm (any ground — J3 pin 3); **PGC** 0.92 mm (J3 pin 5, U1 pin 27); **CAN_TX** 0.94 mm (U1 pin 23, U2 pin 1) |
| 23 | CAN_TX | U2 pin 1 | **SGND** 0.30 mm (any ground — J3 pin 3); **CAN_RX** 0.81 mm (U1 pin 24, U2 pin 4) |
| 24 | CAN_RX | U2 pin 4 | **SGND** 0.30 mm (any ground — J3 pin 3); **CAN_TX** 0.46 mm (U1 pin 23, U2 pin 1) |
| 25 | — | — | **SGND** 0.30 mm (any ground — J3 pin 3); **CAN_TX** 0.67 mm (U1 pin 23, U2 pin 1); **CAN_RX** 0.94 mm (U1 pin 24, U2 pin 4) |
| 26 | — | — | **SGND** 0.30 mm (any ground — J3 pin 3); **PGC** 0.83 mm (J3 pin 5, U1 pin 27) |
| 27 | PGC | J3 pin 5 | **SGND** 0.30 mm (any ground — J3 pin 3); **PGD** 0.84 mm (J3 pin 4, U1 pin 28) |
| 28 | PGD | J3 pin 4 | **SGND** 0.30 mm (any ground — J3 pin 3); **+5V** 0.38 mm (any +5 V pin — J3 pin 2); **~MCLR** 0.46 mm (J3 pin 1, U1 pin 1, R6 pad 2) |

## U2 — MCP2562-E/P

| Pad | Net | Must read **zero** to | Must stay **open** to |
|---|---|---|---|
| 1 | CAN_TX | U1 pin 23 | **SGND** 0.30 mm (any ground — J3 pin 3); **+5V** 0.40 mm (any +5 V pin — J3 pin 2); **PGD** 0.48 mm (J3 pin 4, U1 pin 28) |
| 2 | SGND | any ground — J3 pin 3 | **+5V** 0.40 mm (any +5 V pin — J3 pin 2); **CAN_TX** 0.87 mm (U1 pin 23, U2 pin 1) |
| 3 | +5V | any +5 V pin — J3 pin 2 | **SGND** 0.30 mm (any ground — J3 pin 3); **CAN_RX** 0.94 mm (U1 pin 24, U2 pin 4) |
| 4 | CAN_RX | U1 pin 24 | **SGND** 0.30 mm (any ground — J3 pin 3); **+5V** 0.70 mm (any +5 V pin — J3 pin 2) |
| 5 | +5V | any +5 V pin — J3 pin 2 | **SGND** 0.30 mm (any ground — J3 pin 3); **CANH** 0.42 mm (J1 pin 3, J2 pin 3, U2 pin 7); **CANL** 0.87 mm (J1 pin 4, J2 pin 4, U2 pin 6) |
| 6 | CANL | J1 pin 4, J2 pin 4 | **SGND** 0.30 mm (any ground — J3 pin 3); **CANH** 0.42 mm (J1 pin 3, J2 pin 3, U2 pin 7); **+5V** 0.61 mm (any +5 V pin — J3 pin 2) |
| 7 | CANH | J1 pin 3, J2 pin 3 | **SGND** 0.30 mm (any ground — J3 pin 3); **CANL** 0.94 mm (J1 pin 4, J2 pin 4, U2 pin 6) |
| 8 | SGND | any ground — J3 pin 3 | **+5V** 0.40 mm (any +5 V pin — J3 pin 2); **~MCLR** 0.48 mm (J3 pin 1, U1 pin 1, R6 pad 2); **CANH** 0.94 mm (J1 pin 3, J2 pin 3, U2 pin 7) |

## Y1 — 16MHz

| Pad | Net | Must read **zero** to | Must stay **open** to |
|---|---|---|---|
| 1 | OSC1 | U1 pin 9, C1 pad 1 | **SGND** 0.30 mm (any ground — J3 pin 3) |
| 2 | OSC2 | U1 pin 10, C2 pad 1 | **SGND** 0.30 mm (any ground — J3 pin 3) |

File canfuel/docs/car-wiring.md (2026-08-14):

# Car-side wiring — what each wire in the loom is

A reference for the loom that was actually built into the reference vehicle:
which colour carries what, and where each one is tapped in the car. Kept
because none of it is legible from the wire itself once the dashboard is back
together.

> **This is a record of the car, not of a part.** It was written down while the
> wires were in hand and is transcribed here as recorded — the sourcing rule in
> the top-level `CLAUDE.md` settles facts about the car by observation, and
> this is one of them. Nothing here is derived from a datasheet and nothing in
> the board design depends on it.

⚠ **This page is about the 4-pin between the car and the MFD15's own harness —
the 12 V one.** It is *not* the converter plug. The converter plug is a
different connector, on different nets, with a different circuit order, and it
is in `pinout.md`. The two are easy to confuse and the colours actively
mislead: **black is ground on one and +12 V on the other.**

---

## Car side of the 4-pin

| Circuit | Signal | Wire | Tapped onto |
| --- | --- | --- | --- |
| 1 | ground | brown | — |
| 2 | power (12 V) | black  | black/violet wire, pin 1 of the cluster's **blue** connector |
| 3 | CAN H  | grey | orange/black wire, pin 19 of the cluster's **green** connector |
| 4 | CAN L  | yellow/green | orange wire, pin 20 of the cluster's **green** connector |

## MFD15 side of the same 4-pin — the CANchecked cable

The lead supplied with the display
(<https://www.canchecked.de/mfd15-gen2-52mm-can-bus-anzeige/>).

| Circuit | Signal | Wire |
| --- | --- | --- |
| 1 | ground | black  |
| 2 | power (12 V) | red |
| 3 | CAN H  | white  |
| 4 | CAN L  | yellow |

Circuit for circuit the two halves agree; only the colours differ, which is why
both columns are worth having written down.

---

## How this relates to the rest of the project

- **The 12 V in circuit 2 powers the display, not the converter.** The
  converter's 5 V comes off plug C at C6/C12 and never touches this connector —
  see `harness.md` C3 and `pinout.md`.
- **The CAN pair here is the same pair the converter listens to**, carried on
  to the air vent as the white/yellow run in `harness.md` A2.
- **The circuit order is not the converter plug's order.** Here circuit 1 is
  ground and 2 is power; on the converter plug circuit 1 is +5V and 2 is SGND.
  Do not carry one layout over to the other.

## See also

- `pinout.md` — the three connectors this project's own loom touches
- `harness.md` — building the loom

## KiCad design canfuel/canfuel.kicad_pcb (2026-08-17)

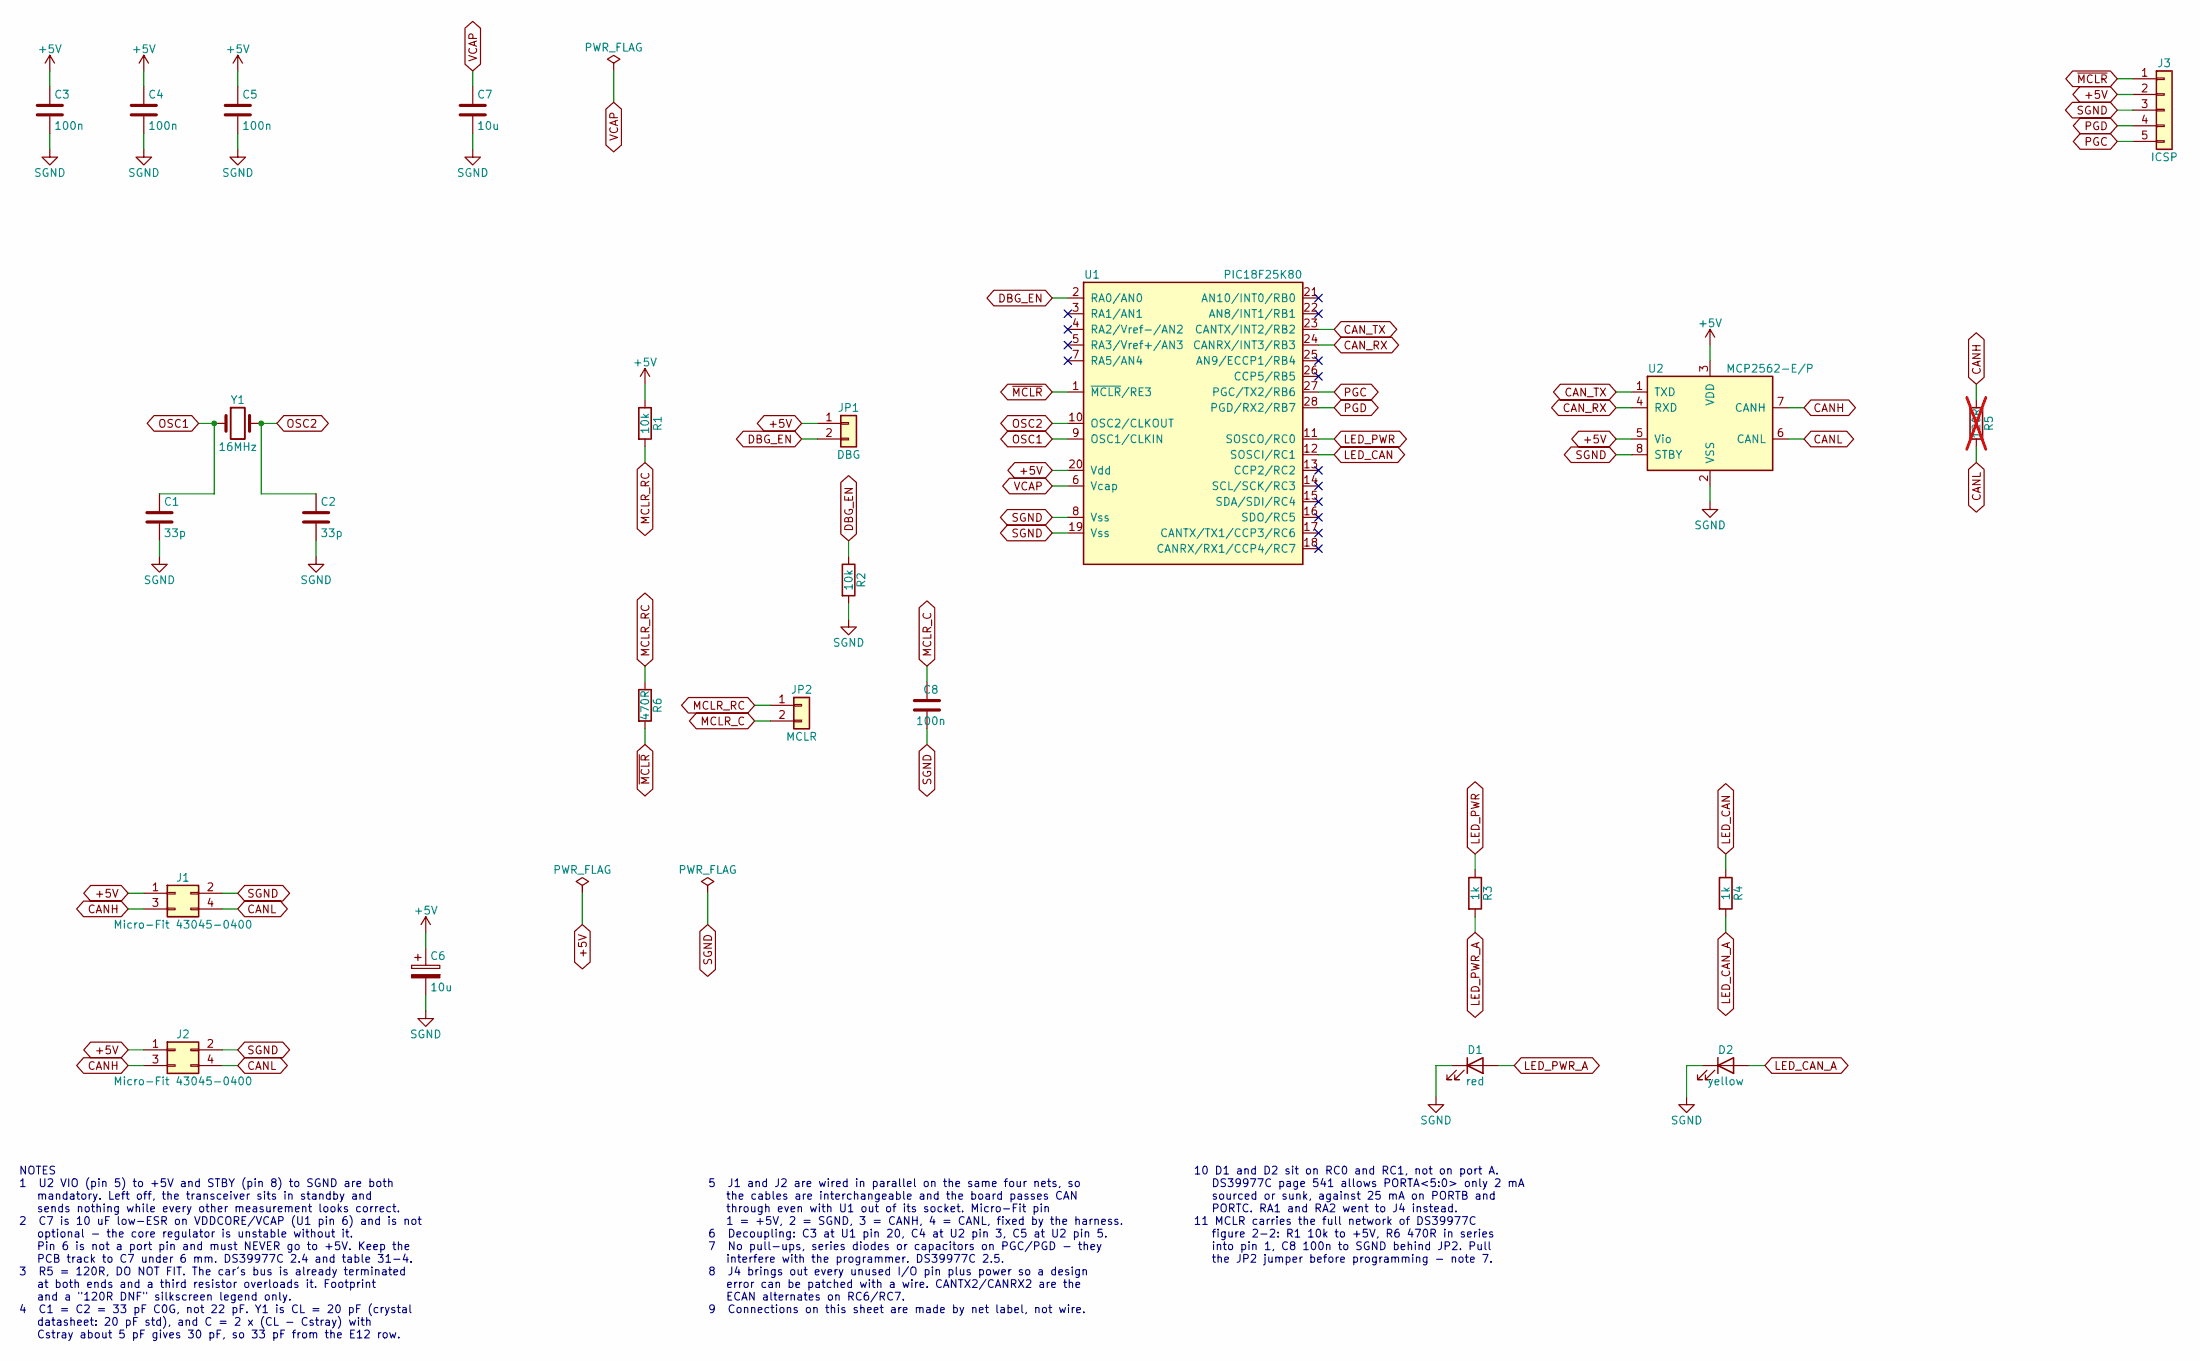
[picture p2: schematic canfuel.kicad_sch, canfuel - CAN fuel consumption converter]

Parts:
C1, C2: 33p; C_Disc_D5.0mm_W2.5mm_P5.00mm
C3, C4, C5: 100n; C_Disc_D5.0mm_W2.5mm_P5.00mm
C6: 10u; CP_Radial_D5.0mm_P2.00mm
C7: 10u; C_1210_3225Metric_Pad1.33x2.70mm_HandSolder
C8: 100n; C_Disc_D5.0mm_W2.5mm_P2.50mm
D1: red; LED_D3.0mm
D2: yellow; LED_D3.0mm
J1, J2: Micro-Fit 43045-0400; Molex_Micro-Fit_3.0_43045-0400_2x02_P3.00mm_Horizontal
J3: ICSP; PinHeader_1x05_P2.54mm_Vertical
JP1: DBG; PinHeader_1x02_P2.54mm_Vertical
JP2: MCLR; PinHeader_1x02_P2.54mm_Vertical
R1, R2: 10k; R_Axial_DIN0207_L6.3mm_D2.5mm_P2.54mm_Vertical
R3, R4: 1k; R_Axial_DIN0207_L6.3mm_D2.5mm_P2.54mm_Vertical
R5: 120R; R_Axial_DIN0207_L6.3mm_D2.5mm_P2.54mm_Vertical; not fitted
R6: 470R; R_Axial_DIN0207_L6.3mm_D2.5mm_P2.54mm_Vertical
U1: PIC18F25K80; DIP-28_W7.62mm_Socket
U2: MCP2562-E/P; DIP-8_W7.62mm_Socket
Y1: 16MHz; Crystal_HC49-U_Vertical

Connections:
+5V: C3.1, C4.1, C5.1, C6.1, J1.1, J2.1, J3.2, JP1.1, R1.1, U1.20 (Vdd), U2.3 (VDD), U2.5 (Vio)
CANH: J1.3, J2.3, R5.1, U2.7 (CANH)
CANL: J1.4, J2.4, R5.2, U2.6 (CANL)
CAN_RX: U1.24 (CANRX/INT3/RB3), U2.4 (RXD)
CAN_TX: U1.23 (CANTX/INT2/RB2), U2.1 (TXD)
DBG_EN: JP1.2, R2.1, U1.2 (RA0/AN0)
LED_CAN: R4.1, U1.12 (SOSCI/RC1)
LED_CAN_A: D2.2 (A), R4.2
LED_PWR: R3.1, U1.11 (SOSCO/RC0)
LED_PWR_A: D1.2 (A), R3.2
MCLR_C: C8.1, JP2.2
MCLR_RC: JP2.1, R1.2, R6.1
OSC1: C1.1, U1.9 (OSC1/CLKIN), Y1.1
OSC2: C2.1, U1.10 (OSC2/CLKOUT), Y1.2
PGC: J3.5, U1.27 (PGC/TX2/RB6)
PGD: J3.4, U1.28 (PGD/RX2/RB7)
SGND: C1.2, C2.2, C3.2, C4.2, C5.2, C6.2, C7.2, C8.2, D1.1 (K), D2.1 (K), J1.2, J2.2, J3.3, R2.2, U1.8 (Vss), U1.19 (Vss), U2.2 (VSS), U2.8 (STBY)
VCAP: C7.1, U1.6 (Vcap)
~MCLR: J3.1, R6.2, U1.1 (~MCLR/RE3)

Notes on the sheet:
NOTES 1 U2 VIO (pin 5) to +5V and STBY (pin 8) to SGND are both mandatory. Left off, the transceiver sits in standby and sends nothing while every other measurement looks correct. 2 C7 is 10 uF low-ESR on VDDCORE/VCAP (U1 pin 6) and is not optional - the core regulator is unstable without it. Pin 6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
5 J1 and J2 are wired in parallel on the same four nets, so the cables are interchangeable and the board passes CAN through even with U1 out of its socket. Micro-Fit pin 1 = +5V, 2 = SGND, 3 = CANH, 4 = CANL, fixed by the harness. 6 Decoupling: C3 at U1 pin 20, C4 at U2 pin 3, C5 at U2 pin 5. 7 No 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
10 D1 and D2 sit on RC0 and RC1, not on port A. DS39977C page 541 allows PORTA<5:0> only 2 mA sourced or sunk, against 25 mA on PORTB and PORTC. RA1 and RA2 went to J4 instead. 11 MCLR carries the full network of DS39977C figure 2-2: R1 10k to +5V, R6 470R in series into pin 1, C8 100n to SGND behi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

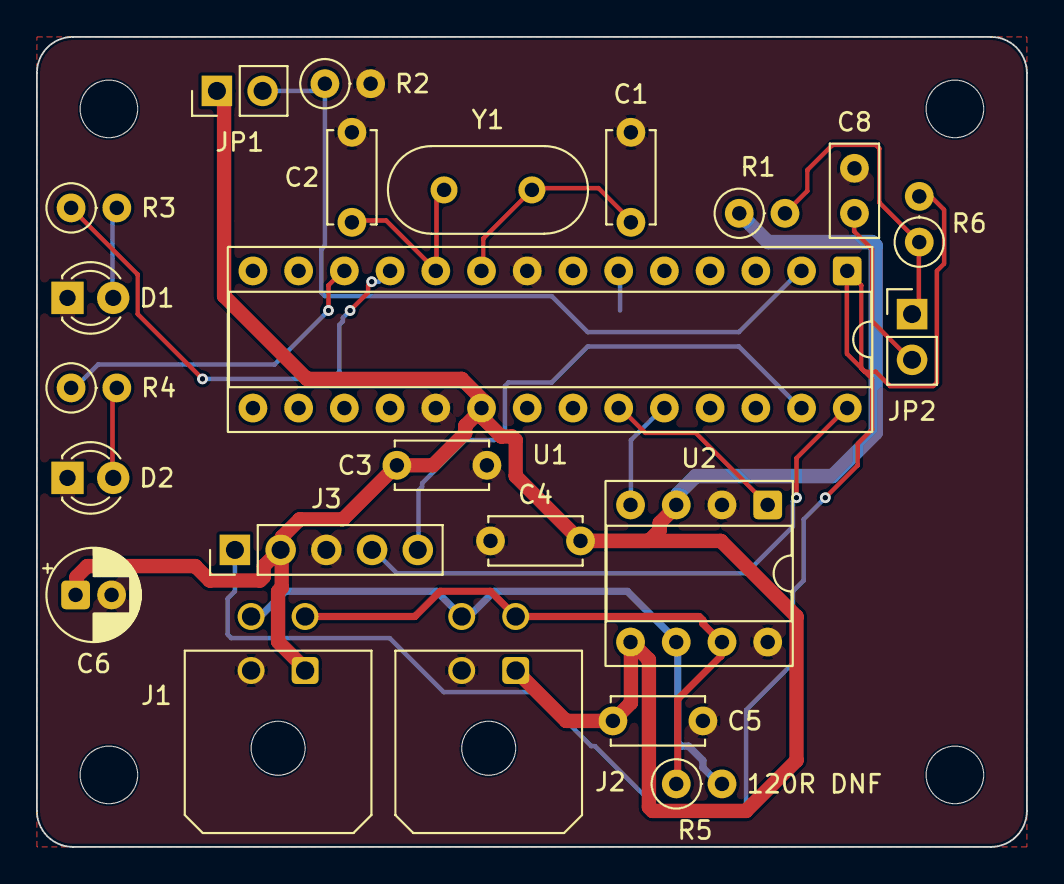
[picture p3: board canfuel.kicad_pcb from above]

Board: 2 copper layers, 55.0 x 45.0 mm, 28 parts (1 on the bottom side), 19 nets.

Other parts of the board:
H1, H2, H3, H4: MountingHole_3.2mm_M3

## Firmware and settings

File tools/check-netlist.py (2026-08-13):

#!/usr/bin/env python3
"""Check canfuel's schematic against its implementation plan.

ERC proves the sheet is electrically well formed. It cannot prove that RB2
went to the transceiver's TXD rather than RB3 - both are bidirectional pins
on a two-pin net either way. This does: it exports the netlist and compares
every ref.pin -> net against the tables in canfuel/docs/implementation-plan.md,
which are typed out below by hand.

    python tools/check-netlist.py

Needs kicad-cli on PATH. Exits nonzero on any mismatch, so it can be wired
into CI later if that turns out to be worth it.

When the design changes on purpose, change EXPECT here in the same commit -
that is the point of the file, not an inconvenience.
"""

import os
import subprocess
import sys
import tempfile

HERE = os.path.dirname(os.path.abspath(__file__))
SCH = os.path.join(os.path.dirname(HERE), "canfuel", "canfuel.kicad_sch")

# --------------------------------------------------------------------------
# Expected connections, from canfuel/docs/implementation-plan.md
# --------------------------------------------------------------------------

EXPECT = {}

# Sentinel for a pin that carries a no-connect flag on purpose. KiCad names
# such a net "unconnected-(U1-RA1{slash}AN1-Pad3)", which is generated from the
# pin's own name and would turn this table into a transcription exercise; what
# is actually being asserted is "nothing is wired here, deliberately".
NC = object()

# 4.2 U1 - PIC18F25K80, the full 28-pin table. Pin 6 is VDDCORE/VCAP and pin
# 20 is Vdd; neither is a port pin and the plan says so twice for a reason.
#
# The LEDs are on RC0/RC1, not RA1/RA2: the Absolute Maximum Ratings on
# DS39977C page 541 allow PORTA<5:0> only 2 mA sourced or sunk, against 25 mA
# for PORTB and PORTC. RA1/RA2 took the RC0/RC1 escape slots in exchange, and
# when the escape header itself went (plan 5.4) all fourteen became NC.
for pin, net in {
        1: "~{MCLR}", 2: "DBG_EN", 3: NC, 4: NC, 5: NC,
        6: "VCAP", 7: NC, 8: "SGND", 9: "OSC1", 10: "OSC2",
        11: "LED_PWR", 12: "LED_CAN", 13: NC, 14: NC,
        15: NC, 16: NC, 17: NC, 18: NC,
        19: "SGND", 20: "+5V", 21: NC, 22: NC,
        23: "CAN_TX", 24: "CAN_RX", 25: NC, 26: NC,
        27: "PGC", 28: "PGD"}.items():
    EXPECT["U1.%d" % pin] = net

# 3.1 MCP2562. Pin 5 (Vio) and pin 8 (STBY) are the two that decide whether
# the board transmits at all.
for pin, net in {1: "CAN_TX", 2: "SGND", 3: "+5V", 4: "CAN_RX",
                 5: "+5V", 6: "CANL", 7: "CANH", 8: "SGND"}.items():
    EXPECT["U2.%d" % pin] = net

# 3.2 crystal and its 33 pF loading
EXPECT.update({"Y1.1": "OSC1", "Y1.2": "OSC2",
               "C1.1": "OSC1", "C1.2": "SGND",
               "C2.1": "OSC2", "C2.2": "SGND"})

# 3.3 termination across CANH/CANL, not fitted
EXPECT.update({"R5.1": "CANH", "R5.2": "CANL"})

# 3.4 both Micro-Fit headers on the same four nets
for j in ("J1", "J2"):
    EXPECT.update({j + ".1": "+5V", j + ".2": "SGND",
                   j + ".3": "CANH", j + ".4": "CANL"})

# 3.5 VDDCORE/VCAP, and 4.4 decoupling
EXPECT.update({"C7.1": "VCAP", "C7.2": "SGND"})
for c in ("C3", "C4", "C5", "C6"):
    EXPECT.update({c + ".1": "+5V", c + ".2": "SGND"})

# 4.3a the MCLR network of DS39977C Figure 2-2, in full: the 10k pull-up, the
# 470 ohm that limits what C8 can dump into the pin if MCLR ever breaks down,
# and the jumper that lifts C8 off the node during programming - section 2.5
# is explicit that a capacitor there interferes with the programmer.
EXPECT.update({"R6.1": "MCLR_RC", "R6.2": "~{MCLR}",
               "JP2.1": "MCLR_RC", "JP2.2": "MCLR_C",
               "C8.1": "MCLR_C", "C8.2": "SGND"})

# 4.2 LEDs and the debug jumper
EXPECT.update({"R1.1": "+5V", "R1.2": "MCLR_RC",
               "R2.1": "DBG_EN", "R2.2": "SGND",
               "JP1.1": "+5V", "JP1.2": "DBG_EN",
               "R3.1": "LED_PWR", "R3.2": "LED_PWR_A",
               "R4.1": "LED_CAN", "R4.2": "LED_CAN_A",
               "D1.1": "SGND", "D1.2": "LED_PWR_A",
               "D2.1": "SGND", "D2.2": "LED_CAN_A"})

# 4.3 ICSP
EXPECT.update({"J3.1": "~{MCLR}", "J3.2": "+5V", "J3.3": "SGND",
               "J3.4": "PGD", "J3.5": "PGC"})

# 5.4 escape hatch: REMOVED, see plan 5.4. The fourteen ESC_*
# labels above are now single-node nets and U1's unused pins carry no-connect
# flags. They stay named because the name is what says which pin is which.
#
# Why it went: with J4 fitted the router left 8 of 39 connections unroutable,
# and five of those eight were not escape signals - both status LEDs and the
# whole ICSP header. A header whose job is to rescue a design error was
# stopping the chip being programmed. Without it the board routes complete and
# DRC clean. Patching now means soldering to the PDIP socket pins underneath.

# Section 2 of the plan, less R5's absence from the BOM which is a separate
# check - see plan section 6.
WANT_REFS = {"U1", "U2", "Y1", "C1", "C2", "C3", "C4", "C5", "C6", "C7", "C8",
             "R1", "R2", "R3", "R4", "R5", "R6", "D1", "D2",
             "J1", "J2", "J3", "JP1", "JP2"}

# --------------------------------------------------------------------------


def parse(text):
    """Just enough S-expression reader for a netlist."""
    pos, out = 0, []
    while pos < len(text):
        while pos < len(text) and text[pos] in " \t\r\n":
            pos += 1
        if pos >= len(text):
            break
        node, pos = _node(text, pos)
        out.append(node)
    return out


def _node(text, pos):
    pos += 1  # the opening paren
    items = []
    while True:
        while text[pos] in " \t\r\n":
            pos += 1
        c = text[pos]
        if c == ")":
            return items, pos + 1
        if c == "(":
            node, pos = _node(text, pos)
            items.append(node)
        elif c == '"':
            pos += 1
            buf = []
            while text[pos] != '"':
                if text[pos] == "\\":
                    pos += 1
                buf.append(text[pos])
                pos += 1
            items.append("".join(buf))
            pos += 1
        else:
            start = pos
            while text[pos] not in ' \t\r\n()':
                pos += 1
            items.append(text[start:pos])


def find(node, tag):
    for child in node:
        if isinstance(child, list) and child and child[0] == tag:
            return child
    return None


def find_all(node, tag):
    return [c for c in node if isinstance(c, list) and c and c[0] == tag]
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

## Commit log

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2026-08-08 Fix CI container permissions and add the canfuel implementation plan
    The ERC and DRC job failed in "Post Run actions/checkout" with EACCES on
    /__w/_temp/_runner_file_commands. The kicad/kicad:8.0 image defaults to the
    unprivileged "kicad" user while the runner creates its working directory as
    root, so the checkout post-step cannot write its state file. Run the container
    as root.
    Also add canfuel/docs/implementation-plan.md: reference designators, the pin
    level connections for the PIC and the MCP2562, net classes, a placement plan
    and the order of commits. The four failure modes called out in CLAUDE.md get a
    section each, plus one new blocking question - whether the 28-pin K80 exposes
    ENVREG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
2026-08-08 Correct the PIC18F25K80 pinout in the implementation plan from the datasheet
    Checked against DS39977C (PIC18F66K80 family), 28-pin SSOP/SPDIP/SOIC diagram
    on page 6, section 2.4 and Table 31-4. Three things were wrong or unstated:
    Pin 6 is VDDCORE/VCAP, not RA4 - the 28-pin K80 has no RA4 at all, and the
    escape header listed one. There is no ENVREG pin anywhere in the family; on
    the F part (not LF) the 3.3 V core regulator is permanently enabled and needs
    10 uF low-ESR to ground within 6 mm of pin 6, and pin 6 must never be tied to
    VDD. That makes C7 mandatory rather than conditional, and gives it the only
    numeric placement constraint on the board.
    Port A is therefore tighter than assumed: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
2026-08-08 Add KiCad project skeleton for canfuel
    The project itself was created in the KiCad GUI so the schema versions are
    right. This commit moves it into canfuel/ per the one-directory-per-board
    rule, applies the Board Setup values from section 1 of the implementation
    plan, and draws the 55 x 45 mm outline.
    The outline is here rather than in the layout commit because DRC treats a
    board with no Edge.Cuts edges as an invalid_outline error, and the whole
    point of this commit is that CI stops being a no-op and goes green on real
    checks. Mounting holes are left out - their positions depend on an enclosure
    measurement that has not happened yet.
    KiCad installed is 10.0.5, not the 8 the plan assumed, so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
    [canfuel.kicad_pcb, canfuel.kicad_sch]
2026-08-08 Draw canfuel schematic
    One A3 sheet, 22 components, 31 nets. A4 was tried first and every block
    collided with its neighbour - the part count is low but the label count
    is not.
    All four failure modes from section 3 of the implementation plan are on
    the sheet and repeated as numbered notes on it, so they survive even if
    someone opens the schematic without the plan: MCP2562 VIO to +5V and STBY
    to SGND, R5 120R not fitted, 33 pF crystal loading, both Micro-Fit headers
    in parallel, and 10 uF on VDDCORE/VCAP with pin 6 never tied to +5V.
    Labels are global rather than local. On one sheet either works, but a
    local label reaches the netlist as /CANH while the net classes in plan
    section 5.3 are wri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
    [canfuel.kicad_sch]
2026-08-08 Give the CI container a HOME with KiCad libraries in it
    Running the job as root fixed the checkout permission problem but moved
    HOME to /root, where KiCad finds no symbol or footprint library table.
    Reproduced locally by pointing KiCad at an empty config directory: ERC on
    the committed schematic then reports 64 lib_symbol_issues and
    footprint_link_issues warnings, and --exit-code-violations turns those
    into a failed job even though the design is fine.
    HOME=/home/kicad is the image's own KiCad user, so the standard libraries
    resolve. Fixing the environment rather than lowering the ERC severity -
    lib_symbol_issues catches a cached symbol drifting from its library,
    which is worth keeping.
    Co-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
2026-08-08 Stop the CI checks depending on bash
    Both check steps opened with "shopt -s globstar nullglob", which is a bash
    builtin. Whatever shell the kicad container actually gives a run: block, it
    is not that one - the step failed on every run since it was written,
    including runs where the repo held no schematic and the loop had nothing to
    do. That is what identified it: a step that fails with zero input files is
    failing before it reads any.
    Rewritten in plain POSIX shell - find walks the tree, a while-read loop
    consumes it - so it no longer matters which shell runs it. Verified locally
    against a POSIX sh in three cases: this repo (exit 0), a directory with no
    design files (skips, exit 0), and two b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
2026-08-08 Add the netlist check as a script, and hand over cleanly
    Section 4.6 of the implementation plan told the reader to re-compare the
    netlist against the plan after any edit to the schematic, but the thing that
    does the comparing lived outside the repository, which made the instruction
    useless. It is now tools/check-netlist.py.
    It earns its place. Swapping the labels on U1 pins 23 and 24 - CANTX and
    CANRX crossed at the MCU, a board that could never transmit - passes ERC
    with zero violations, because both pins are bidirectional and the sheet is
    perfectly well formed. That was tried rather than asserted; the script
    catches it and names both pins.
    CLAUDE.md also gains a short section on the loca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
    [check-netlist.py]
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2026-08-08 Stop the permission prompts from getting in the way of the checks
    The local settings carried 75 command-prefix allow rules and still prompted on
    almost every verification step. Prefix rules match the start of a command, and
    the real invocations here are compound - a variable assignment, a cd, a
    kicad-cli call and a python heredoc chained together - so each new shape fell
    outside every rule and asked again. The effect of a prompt on ERC, DRC,
    check-netlist.py or a render is that they get run less, which is the opposite
    of what they are for.
    Replaced with defaultMode "dontAsk" plus ask rules on git commit, git push,
    gh pr create, git rebase and git reset --hard: the operations that leave the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
2026-08-08 Drop the enclosure and put the mounting holes in
    The enclosure has blocked the layout since the project started, on the grounds
    that the M3 hole positions were a guess until it was measured and were the one
    thing that could force a respin. Closing it by choosing a box turned out to be
    the wrong move; closing it by not having one is the right one.
    A box was buying nothing here. Everything around the board in the vent is
    plastic, so there is no metal to short against. The vent is closed off by a
    flap, so there is no airflow, no meaningful dust and no water. The board is
    invisible either way. That leaves mechanical retention, and standoffs buy that
    better than a box does.
    The measurement argu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
    [canfuel.kicad_pcb]
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2026-08-09 Place canfuel PCB parts
    Net classes, all 25 footprints, and a silkscreen that can be read. Nothing is
    routed yet; DRC is clean and the 70 unconnected items are the ratsnest.
    The MCLR network cannot meet DS39977C 2.3 in full. Four parts totalling 71 mm2
    of courtyard do not fit in the ~85 mm2 of free area around a corner pin of a
    DIP-28, whatever footprints are chosen. R6, the series resistor in the reset
    path, is inside the 6 mm circle entirely; C8 and JP2 sit 4.31 and 2.04 mm away
    at their near edges; R1, the static pull-up, is the one pushed out. Those
    figures are recorded in ALLOW in tools/check-placement.py with their reasons.
    R1-R6 became upright P2.54mm parts and C8 a 2.50 mm disc. Th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
    [canfuel.kicad_pcb, canfuel.kicad_sch]
2026-08-09 Route canfuel PCB, and drop the escape header
    DRC is clean with zero unconnected items. Two layers, SGND poured on both,
    thermal reliefs on every pad because the board is hand soldered.
    J4 is gone, and it went on measurement rather than argument. Routing the same
    placement with the same router, with and without it:
    with J4 without J4
    connections 39 25
    left unroutable 8 0
    DRC incomplete 0 violations
    Five of those eight failures were not escape signals: both status LEDs and the
    whole ICSP header. J4's fourteen signals congest the channel between U1's pin
    rows, which is the only way across a 55 x 4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
    [canfuel.kicad_pcb, canfuel.kicad_sch]
2026-08-09 Make CI fail on an empty file list, and run both checkers
    Two gaps found while verifying the last push through the GitHub API.
    Finding no design files was a note, not an error. The steps printed "no
    schematic in the repo, skipping" and passed on an empty list, so green meant
    either "checked and clean" or "opened nothing at all" with no way to tell them
    apart. That is the globstar bug wearing the opposite mask: back then a broken
    loop failed loudly on zero files and that is what gave it away, whereas this
    would have stayed quiet. This repository will never again be without design
    files, so a run that opens none of them is broken rather than lucky.
    CI also only ran ERC and DRC, which prove t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
2026-08-09 Move R1 1.20 mm clear of C8
    R1 pad 2 and C8 pad 1 are MCLR_RC and MCLR_C - the two ends of JP2 - and
    the search that placed the MCLR cluster left 1.06 mm of bare board between
    them, with the courtyards touching at 0.03 mm. A solder bridge there would
    hold the jumper closed for good, which is the one failure JP2 exists to
    prevent, and the board would look fine until the first attempt to program
    it.
    Moving R1 west by 1.20 mm opens that gap to 2.26 mm. The move is sized by
    the nearest-edge rule rather than by eye: R1 lands at 2.89 mm, inside the
    3 mm assertion with a little margin, and costs about 0.9 mm of extra track
    to the MCLR node - which R1, the 10k static pull-up, is the right part to
    s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
    [canfuel.kicad_pcb]
2026-08-09 Fuse the 5 V feed, in the harness rather than on the board
    The board takes 5 V straight from the display, so a short on it is a short
    across the MFD15's 5 V rail. This adds a fuse, and records why it is not on
    the PCB: the largest free rectangle left on a finished 55 x 45 mm board is
    12.2 x 15.2 mm, and a 5 x 20 holder lying flat needs about 24 x 7. Measured,
    not estimated. The alternatives were a holder standing 25 mm tall against a
    vent depth that has never been measurable, or soldering the fuse down, which
    gives up the only thing a cartridge fuse is for. Nothing about the schematic,
    the PCB or the four checks changes.
    A cartridge fuse beats a resettable PTC here because pulling the MFD15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
2026-08-09 Turn harness.md into a build document, and close the last open question
    The measuring, the TRI check and both sniffs have been done, so everything in
    harness.md that existed to prove those points is gone. What is left is how to
    make the loom: bench work, the fuse splice, routing in the car, finishing.
    149 lines down to 110. The intro says the tests were done rather than leaving
    a silent gap, so that in six months their absence does not read as an
    oversight.
    The car-side 4-pin connector is no longer an open question either. The
    connector exists and is fitted, so the loom is a re-crimp onto longer wires,
    not a choice to make. That was the last row in the plan's open-questions table
    and the ta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
2026-08-09 Add canfuel fabrication outputs, and the 120R DNF legend they were missing
    Plan section 6. canfuel/fab/ now holds nine gerbers, a merged Excellon drill
    file, a drill map, a .gbrjob, the BOM and the CPL. The plan records the exact
    commands: four of the kicad-cli defaults are wrong for this board, so the flags
    are part of the design, not shell noise. --layers is required at all,
    --check-zones stops a stale pour being what gets sent, --format csv --units mm
    keeps export pos from writing an ASCII-in-inches file named .csv, and
    --exclude-dnp keeps R5 out of the placement file.
    The pre-order check in section 6 earned its keep. R5 is the 120 ohm
    termination that must not be fitted, and the silkscr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
    [canfuel-B_Cu.gbl, canfuel-B_Mask.gbs, canfuel-B_Paste.gbp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]
2026-08-09 Size the silkscreen for a real process, and give the rule teeth
    printed.cz is the first fab house looked at. Everything on this board clears
    their limits with room - track and spacing are above the value their page
    recommends, not just above the minimum - except the legend, and there it failed
    on all 25 items. Every silkscreen text was 0.80 mm high with a 0.12 mm stroke
    against their 1 mm and 0.15 mm minimums. All 25 are now 1.0 / 0.15, which is
    what silk_text_size_h/v and silk_text_thickness in the project defaults had
    said all along; only the placed items disagreed. Nothing had to move.
    Our own DRC could not have caught this: min_text_height was 0.8 and
    min_text_thickness 0.08, looser tha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
    [canfuel-B_Cu.gbl, canfuel-B_Mask.gbs, canfuel-B_Paste.gbp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]
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2026-08-09 Make the board 1.5 mm, to match the stack-up actually being ordered
    Gatema's POOL service sells fixed stack-ups and every two-layer one is 1.5 mm.
    The preset chosen is 2V Cu 35/35 um, 1,5 mm, LF HAL, 2x green mask, 1x white
    legend, Tg 135 C.
    Nothing on the board depends on the 0.1 mm. The via aspect ratio moves from
    1:5.3 to 1:5.0 against a 1:10 limit, lead-free HAL wants 0.8-2.5 mm, and
    SD-43045-001 only recommends 1.57 mm for the Micro-Fit - 1.5 mm is under it,
    which is the safe direction for a snap-in peg because the barb protrudes
    further below the board.
    What did matter is that canfuel-job.gbrjob declared BoardThickness 1.6.
    Ordering one number while shipping a job file that states an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
    [canfuel-B_Cu.gbl, canfuel-B_Mask.gbs, canfuel-B_Paste.gbp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]
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2026-08-10 Say which Micro-Fit cavity each harness wire goes in
    harness.md never recorded it, so the question came up with the loom half
    built and the answer had to be worked back out of plan 3.4 and the J1/J2
    pads. Step A4a now carries the table, and says to find the cavities from
    the moulded 1 rather than by counting from an end -- from the wire side
    the numbering is the mirror of the mating face, which is exactly how a
    pair gets swapped.
    Two drawings go with it, both generated from the pad coordinates in
    canfuel.kicad_pcb rather than drawn by hand: harness-connector.svg for
    the plug and the pads, harness-nets-on-pcb.svg for the same four nets on
    the real copper, turned the way up the 1:1 paper prin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
2026-08-11 Licence the repository under Apache-2.0, and declare what is not ours
    The README has said "not decided yet" since the repository was created.
    It is decided: Apache License 2.0, unmodified, as published.
    Apache-2.0 rather than MIT for one reason that actually matters here --
    NOTICE. This repository redistributes manufacturer documents it does not
    own, and section 4(d) of Apache-2.0 defines a NOTICE file whose
    attribution text has to be carried into derivative works. That is the
    standard, licence-native place to say "these files are not covered", and
    no shorter licence has one.
    To be exact about what NOTICE does and does not do: it *declares* the
    third-party material, it does not licence it.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
2026-08-11 README and CLAUDE.md: correct three stale claims and one contradiction
    The README described a repository that stopped existing months ago:
    - "design not started" for a board that is finished, checked, ordered
    from Gatema on 2026-08-09 and being manufactured as commit c06e710.
    - "KiCad 8", where CLAUDE.md, the implementation plan and the CI
    container image all say KiCad 10. The version is load-bearing here --
    KiCad refuses to open files written by a newer major version -- so
    disagreeing with itself about it is worse than usual.
    - "The workflow currently runs as a skeleton -- while the repo contains
    no .kicad_sch, it passes doing nothing." It has contained one since the
    design lan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
2026-08-11 CLAUDE.md: point at the shared refuted-hypotheses file
    The escape header and the enclosure are the two ideas in this repository
    most likely to be proposed again by someone reasoning from first
    principles, and both are already argued at length here. They are now also
    entries D1 and D2 in canfuel/docs/refuted.md, which collects the same
    kind of thing from all three repositories.
    One file rather than three, because a good idea that was tried and failed
    is worth finding whichever repository somebody happens to be standing in.
    The detail stays here; the index is there.
    Claude-Session: https://claude.ai/code/session_01UC4v8QiH5kxCUeC3ZWQDVd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
2026-08-11 implementation-plan: stop describing a header that is not on the board
    J4, the escape header, was removed on 2026-08-09 and section 5.4 records
    exactly why. The rest of the document had not caught up: 36 mentions, of
    which only 4 were struck through or dated. The dangerous ones were not
    the prose but the reference material, because that is what somebody opens
    to look something up.
    - **4.2, the full pin table.** Fourteen rows said "J4 (escape)" for pins
    that on the manufactured board go nowhere at all. They now say
    "nothing -- see 3.6", which is both true and a pointer to the firmware
    obligation that replaces the header.
    - **3.6** said the fourteen pins "sit at a header with nothing on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
2026-08-11 harness: the loom is built, and the fuse holder got taped over
    A6 and B4 are done, including B4's second half -- pulling the fuse and
    confirming the circuit really opens, which is the half that proves no splice
    quietly bypasses it. 5.01 V reads through to the 4-pin, matching what was
    measured at C6/C12 before the loom existed, so there is no drop across the
    fuse or the splices.
    D2 was overridden on the build and says so rather than being quietly wrong.
    The intent was that the fuse could be changed without unwrapping anything, but
    one end of the holder leaves bare 5 V exposed, and loose bare metal behind a
    dashboard was judged the worse risk. It is taped over with the rest of the
    loom. The c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
2026-08-13 Cite the J3 pinout, and scope the datasheet rule to what it is for
    Two halves of one problem: the sourcing rule was not being met, and part of the
    reason is that as written it cannot be.
    The citation first. Plan 4.3 has stated the J3 pin order for months under the
    words "PICkit pin order" with nothing behind it -- the neighbouring citation to
    DS39977C 2.5 covers pull-ups, series diodes and capacitors on PGC/PGD, which is
    a different question, and 2.5 carries no connector pinout at all. The source is
    DS51795B Figure 1-2, now in canfuel/docs/pickit3-users-guide.pdf, and it agrees
    with the table exactly. Two things it adds: their connector is six pins where
    J3 is five, because pin 6 is PGM (LV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
2026-08-13 D1 is red: the parts were tested before fitting
    The two LEDs actually going on the board were checked on a multimeter's diode
    range, both reading Vf around 1.8 V, and the choice landed on red for D1 rather
    than green. Yellow for D2 is unchanged.
    Changed at the source and propagated, rather than in prose: the schematic's
    Value field for D1, then canfuel-bom.csv regenerated with the kicad-cli command
    in plan 7. Exactly one line of the BOM moved and the format did not drift,
    which is the point of regenerating rather than editing it. The parts table in
    plan 2 and the reasoning here follow.
    One derived number moved with it. The LED paragraph costed the range at Vf = 2 V
    and Vf = 3.2 V, giving 2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
    [canfuel-bom.csv, canfuel.kicad_sch]
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2026-08-13 CLAUDE.md: what the board is, not how it came to be
    778 lines to 712. The "Current state" section was a 210-line running commentary
    on an order, a fab house, a price, a parts wait and which paragraph had been
    wrong the week before. What it actually needed to say fits in three lists.
    Kept, because these are the decisions that ERC, DRC and both check scripts are
    blind to, and nothing else stands between them and a well-meaning edit: the
    silkscreen text rules being errors rather than warnings, the 120R DNF legend
    being a board-level gr_text, the split PTH/NPTH drill files and why a plated
    peg hole cracks a Molex housing, R1's deliberate offset, the fuse living in the
    harness, and the three out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
2026-08-13 Generalise the plan, the harness and the README
    Third file of the pass, plus the smaller documents around it.
    implementation-plan.md loses all 17 dates and every "this used to say"
    correction note. Those existed because the plan is corrected in place rather
    than rewritten, and quoting the superseded text was how a decision was kept
    from looking like an oversight. With the history in git and a tag on it, the
    quotes are cost without benefit -- what survives is the decision itself, stated
    once.
    Section 6.0 was an order: a fab house, a price, a stack-up preset in Czech, a
    commit hash and a note about how many connectors an invoice covered. It is now
    "what to send a fab house" -- the stack-up a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
2026-08-13 Write down the physics that sizes the passives
    The plan records what each part is and which datasheet section forced it. It
    does not say why the physics needs a part there at all, which is the question
    that actually comes up: why 100 nF and 10 uF are not the same part in two
    sizes, why the 6 mm placement rule is the value rule's equal, and why C6 gives
    hundreds of microseconds of ride-through rather than the milliseconds it looks
    like it should.
    canfuel/docs/components.md is that reasoning, worked from the transceiver's
    40 mA dominant-bit step: the harness cannot serve it, C4 covers the edge, C6
    covers the bit, and C7 covers neither because it is not on the rail.
    Which is a correction, not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
2026-08-17 Draw which way round the five parts that can go in backwards go
    The board's silkscreen already names every part, so a placement drawing that
    only repeats the designators is worth nothing on the bench. What it states only
    as a notch and a flat is orientation, and five parts on this board can be fitted
    the wrong way: D1, D2, C6, U1 and U2.
    tools/render-assembly.py draws both sides out of canfuel.kicad_pcb -- outline,
    pour, tracks, silk, pads, designators and the values of the parts a wrong-slot
    swap is a real hazard on -- and puts a + / - badge on the pads that decide it.
    The polarity comes out of the netlist rather than a table in the script: the
    LED cathode is whichever pad is on SGND, C6'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
2026-08-17 D1 is red in the board too, and fab/ deliberately still says green
    The schematic and the board each carry their own Value field. kicad-cli takes
    the BOM from one and the CPL from the other, so when D1 was changed to red in
    the schematic alone, fab/canfuel-bom.csv said red and fab/canfuel-cpl.csv said
    green and nothing complained. Neither ERC, DRC, check-netlist.py nor
    check-placement.py reads Value; only import-footprints.py writes it, and that
    is the step that was skipped. What found it was render-solder-check.py printing
    the board's copy at the head of D1's table.
    fab/ is left alone on purpose. It is the record of what was sent to the
    manufacturer and the boards on the bench were made fro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
    [canfuel.kicad_pcb]
